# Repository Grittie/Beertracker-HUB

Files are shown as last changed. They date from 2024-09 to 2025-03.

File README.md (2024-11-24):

# IoT Start Project

This is your IoT Gitlab project. You can use it to store your code and documentation. 

## Getting Started

This project contains a setup using Docker. This will help you setup all the necessary tools to start developing your IoT project.
Before you run the docker-compose command, make sure you have to make changes to the configuration. You can find these in
the `.env` file.

Now, to install and start your project; run the following command in the root of your project:

```bash
docker-compose up -d
```

If everything runs correctly, you should be able to visit your website at [http://localhost/](http://localhost/).

## Structure

There is a specific structure that you should follow when developing your project. This will help you to keep your project organized and easy to understand.

**Documentation**

All the documentation of your project should be placed in the `docs/` folder. This will be used for your portfolio-website.

```bash
├── docs/
```

**Embedded**

Everything you need to run your embedded application should be placed in the `embedded/` folder. This includes the source code like .ino-files from Arduino.

```bash
├── embedded/
```

**Web**

Everything you need to run your web application should be placed in the `web/` folder. This includes the source code like PHP, HTML, CSS, Javascript and images.

```bash
├── web/
```

You can visit your website by going to [http://localhost/](http://localhost/) in your browser. And you can find your IoT dashboard at [http://localhost/dashboard](http://localhost/dashboard).

## Database details

The database is a MySQL database using MariaDB. You can connect to it using the following details:

| Parameter | Value |
| --- | --- |
| Host | `mariadb` (from PHP) `localhost` (from your laptop) |
| Port | `3306` |
| Username | `root` |
| Password | You can find this in your .env-file. |
| Database | You need to create the database yourself. |

## Pages
The documentation github page can be found [here](https://grittie.github.io/Beertracker-HUB/)

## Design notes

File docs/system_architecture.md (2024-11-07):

## **System Architecture**

### **Introduction**

The **System Architecture Diagram** provides an abstraction of the entire clock-in/clock-out system. It shows the interaction between the embedded system (ESP32-S3), frontend, backend, database, and the networking components. This diagram is essential to understand how the hardware and software components are connected, enabling smooth communication and efficient logging of user check-ins/outs and sensor data (e.g., temperature and humidity). This architecture also ensures the system is scalable and maintainable for future expansions.

### **Component Breakdown and Functionality**

#### **Embedded System (Subsystem)**

- **ESP32-S3-WROOM-1** (Hardware Component): The core microcontroller responsible for controlling the RFID scanning, user interaction through buttons and LEDs, and communicating with the backend system. It also handles temperature and humidity data acquisition via the DHT11 sensor.
  
- **PN532 RFID Reader** (Hardware Component): This module scans RFID cards and retrieves user information for clocking in and out. It communicates with the ESP32 via I2C.

- **DHT11 Sensor** (Hardware Component): A temperature and humidity sensor that continuously monitors the environment and sends data to the ESP32.

- **Buzzer/LEDs** (Hardware Components): Provide user feedback during operations, such as successful or failed RFID scans.

- **C/C++ Program** (Software Component): The firmware running on the ESP32 that handles input from the sensors, communication with the web server, and control of the system’s outputs (LEDs, buzzer).

#### **Webserver (Subsystem)**

- **NGINX Web Server**: Acts as a reverse proxy, directing traffic to the backend PHP services that handle API requests.
  
- **PHP Module** (Software Component): Responsible for processing HTTP requests, interacting with the database, and managing user sessions.

#### **Frontend (Subsystem)**

- **HTML Files** (Software Components): Define the structure of the web interface where users can view their clock-in/clock-out records and session data.

- **CSS Files** (Software Components): Provide the styling and layout for the web interface.

- **JavaScript Files** (Software Components): Handle frontend logic, fetch data from the backend (using AJAX/HTTP requests), and update the page dynamically.

- **Frontend PHP Files** (Software Components): Handle the dynamic generation of the HTML content, ensuring the frontend is connected to the backend API.

#### **Backend (Subsystem)**

- **API PHP Files** (Software Components): These files handle the logic for user authentication, session management, and communication with the embedded ESP32 system. The `api.php` delegates requests to handlers (e.g., `temperature_handler.php`, `card_handler.php`, `session_handler.php`) based on the type of data being processed.

- **Backend Libraries** (Software Components): These libraries provide support for managing sessions, database queries, and user authentication.

#### **Database System (Subsystem)**

- **MariaDB Database**: Stores all user data, RFID card associations, session logs, and temperature readings. Each session includes data like the check-in/check-out time and the number of pitchers.

- **Database Instance**: The actual instance running within a Docker container, handling all the persistent data storage.

#### **Docker Registry (External System)**

- **Docker Images**: Pre-built containers for PHP, MariaDB, and supporting services, facilitating a portable and consistent environment across development and production.

#### **Docker Host (Subsystem)**

- **Docker Network** (Virtual Hardware Component): Provides network communication between containers running the webserver, backend, and database services.

- **Docker Containers** (Virtual Hardware Component): Run the isolated instances of the webserver (NGINX + PHP) and MariaDB database.

#### **Host System (Subsystem)**

- **Linux (or your specific host OS)**: The operating system running the Docker containers and managing the clock-in/clock-out system.

#### **Mobile Device (External System)**

- **Mobile OS (e.g., Android/iOS)**: Allows users to interact with the system via a web browser to view their clock-in and clock-out logs.

- **Browser**: Accesses the frontend web interface for monitoring and interacting with the system.

#### **Network Access Point (External System)**

- **Wi-Fi Access Point**: Connects the ESP32 to the local network, enabling it to communicate with the backend server over HTTP.

#### **Internet/Intranet (Abstraction)**

- **Cloud Symbol**: Represents the internet or intranet that connects the mobile devices and ESP32 to the server.

#### **SSH Tunnel (Subsystem)**

- **SSH Tunnel**: Provides secure remote access to the server, allowing you to manage and monitor the system from external networks.

---

### **Communication Overview**

- **I2C Protocol (ESP32 <-> PN532, DHT11)**: Used for the ESP32 to communicate with the RFID reader and temperature sensor.
  
- **HTTP Protocol (ESP32 <-> Webserver)**: The ESP32 sends RFID data, user credentials, and sensor data via HTTP requests to the PHP backend.
  
- **HTTPS Protocol (Browser <-> Webserver)**: Users access the frontend interface over HTTPS to ensure secure transmission of data.

- **MySQL Protocol (PHP Backend <-> MariaDB)**: Used by the backend PHP files to query and store data in the database.

- **Docker Networking (Internal)**: Communication between Docker containers (NGINX, PHP, MariaDB) happens over an internal network using standard Docker networking mechanisms.

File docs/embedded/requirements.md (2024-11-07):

# Requirements

This document outlines the hardware *and* functional requirements for the **Smart Time Registration Device**. The system is based on an ESP32-S3-DevKitC-1-N8R8 and is designed to handle RFID-based user identification, API communication, provide user interaction through buttons to cycle between actions, LEDs, and a buzzer.

---

## Hardware Components

- **Microcontroller**: ESP32-S3-DevKitC-1-N8R8
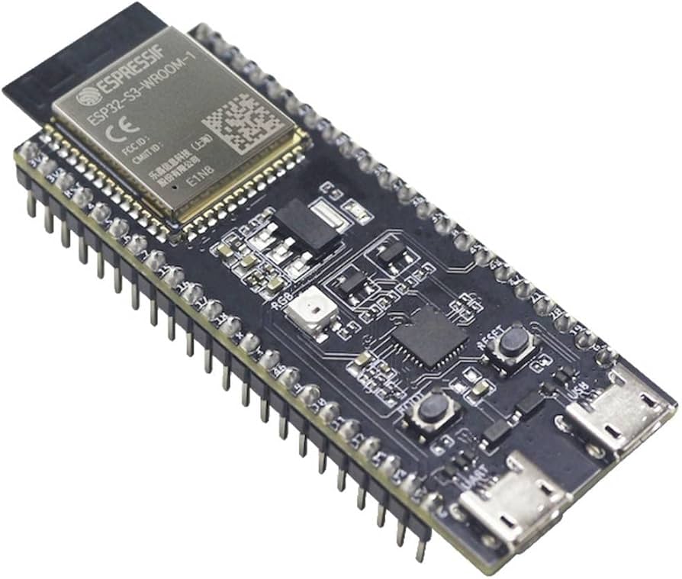
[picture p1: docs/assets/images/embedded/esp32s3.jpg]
Image of an ESP32
<br> 

- **RFID Sensor**: RFID-RC522 for scanning HVA IDs
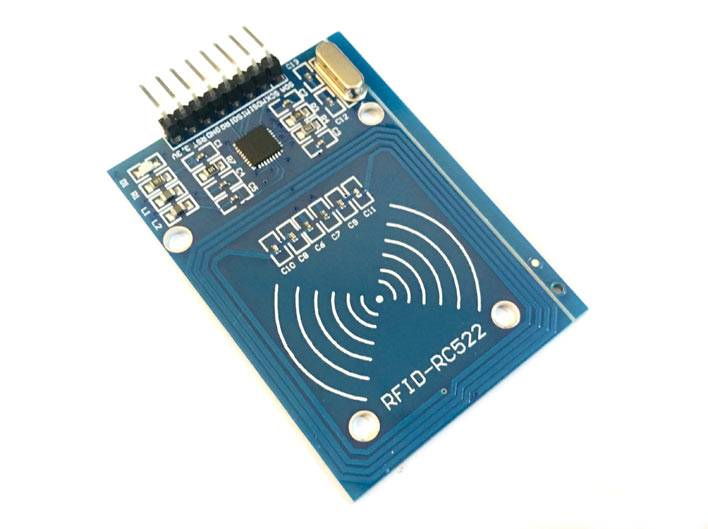
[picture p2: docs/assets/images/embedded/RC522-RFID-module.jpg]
Image of a RFID-RC522 Sensor
<br> 

- **LCD Display**: 16x2 LCD with I2C Backpack
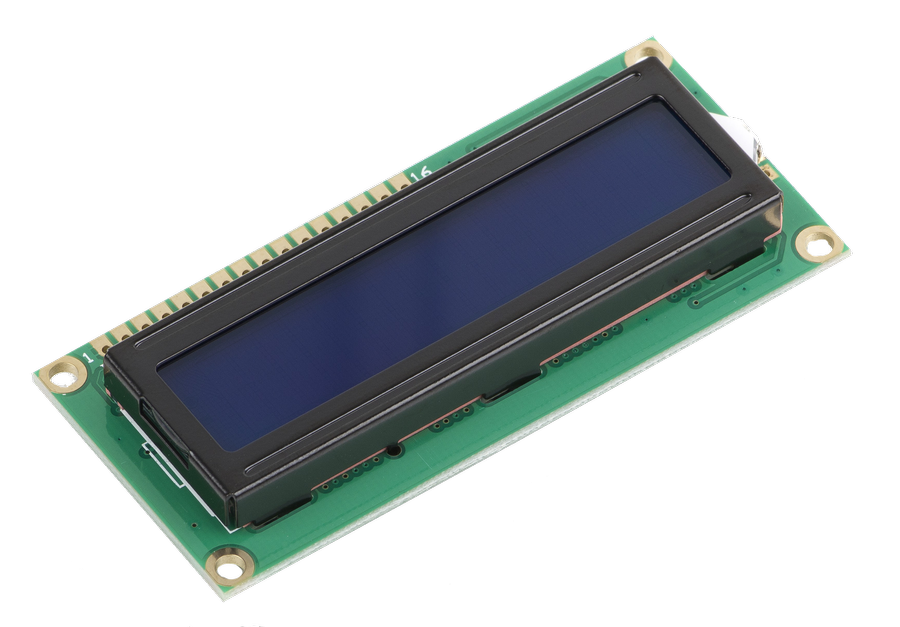
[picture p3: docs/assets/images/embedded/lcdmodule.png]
Image of a 16x2 LCD
<br> 

- **Buzzer**: For feedback on card scan
- **LEDs**: Multiple for system status indication
- **Buttons**: For switching between actions (e.g., Clock In, Clock Out, Start Break, End Break)
- **Connectivity**: Wi-Fi for making API calls to the website
---

## Functional Requirements

### 1. **RFID Scanning**
   - The system will use the RFID-RC522 RFID sensor to scan user HVA IDs.
   - Upon scanning, the system will push the ID data via an API call.

### 2. **API Communication**
   - The ESP32-S3 will connect to the internet to make API calls:
     - **Send scanned data** (RFID) to the server.
     - **Receive user data** (e.g., user name) in response and display on the LCD.

### 3. **Display and Feedback**
   - The LCD screen, connected via I2C, will show user information and action statuses.
   - The buzzer will sound when a card is successfully scanned.
   - LEDs will provide status indications for:
     - Power (system turned on)
     - Internet connectivity (connected/disconnected)
     - Card scan status (success/failure)

### 4. **User Input and Actions**
   - The system will have buttons to switch between different actions:
     - Clock In
     - Clock Out
     - Start Break
     - End Break

---

## Inputs and Outputs

| **Component** | **Type**  | **Function** |
|---|---|---|
| **ESP32-S3-DevKitC-1-N8R8** | MCU | Microcontroller to handle processing and communication. |
| **RC522** | Input | Reads RFID cards to identify users. |
| **LCD Display** | Output | Displays the user name and system statuses. |
| **Buzzer** | Output | Emits sound on successful card scan. |
| **LEDs** | Output | Shows system status: Power, Internet Connectivity, and Card Scan result. |
| **Buttons** | Input | Allows the user to switch between actions (Clock In, Clock Out, etc.). |

---

## System Workflow

1. **Power On**: System starts, LEDs indicate power and system status.
2. **Internet Connection**: LED indicates when the system is connected to the internet.
3. **RFID Scan**: User scans their ID card using the RC522 sensor.
4. **API Call**: The ESP32-S3 sends the RFID data to the server via API.
5. **API Response**: System receives user information and displays it on the LCD screen.
6. **Action Selection**: User selects the action (Clock In/Out, Start/End Break) via buttons.
7. **Feedback**: Buzzer sounds when a card is scanned, LEDs change based on status (e.g., card scan success).

---

## DLO Requirements

| **Requirement ID#** | **Requirement** | **MoSCoW** | **Compliant** |
|---|---|---|---|
| **EMBRQ#01** | The embedded device acts as a client and sends measured sensor data to the application backend over HTTP or HTTPS. | MUST | YES |
| **EMBRQ#02** | The embedded device also acts as a server and receives status messages from the application backend over HTTP or HTTPS. | MUST | YES |
| **EMBRQ#03** | The embedded device contains at least two types of input sensors (e.g. LDR, buttons, joystick, capacitive touch, etc.). | MUST | YES |
| **EMBRQ#04** | The embedded device contains at least two types of visual and/or sensory outputs (e.g. LED, LED Matrix, 7-segment display, motor, servo, actuator, LCD-screen, buzzer, etc.). | MUST | YES |
| **EMBRQ#05** | The embedded device uses the WifiManager for configuration of SSID and password (PWD) for connecting to the network. | MUST | YES |

---

### EMBRQ#01

**Requirement**: The embedded device acts as a client and sends measured sensor data to the application backend over HTTP or HTTPS.

**Explanation**:  
The code uses the `HTTPClient` library to send data to the backend API. This is implemented through a function that collects temperature and humidity data from the DHT sensor and then sends it using an HTTP POST request to the server.

**Code**:
```cpp
#include <HTTPClient.h>
#include <DHT.h>

#define TEMP_SENSOR 26 // Analog Pin
#define DHTTYPE DHT11  // DHT 11 type sensor

DHT dht(TEMP_SENSOR, DHTTYPE);

void sendSensorData() {
    HTTPClient http;
    String serverPath = "http://your-server.com/api.php";
    
    // Read temperature and humidity
    float temperature = dht.readTemperature();
    float humidity = dht.readHumidity();

    // Start connection and send HTTP header
    http.begin(serverPath);
    http.addHeader("Content-Type", "application/json");
    
    // Create JSON payload
    String jsonPayload = "{"temperature": " + String(temperature) + ", "humidity": " + String(humidity) + "}";
    int httpResponseCode = http.POST(jsonPayload);
    
    // End connection
    http.end();
}
```

---

### EMBRQ#02

**Requirement**: The embedded device also acts as a server and receives status messages from the application backend over HTTP or HTTPS.

**Explanation**:  
The code uses the `ESPAsyncWebServer` library to create an HTTP server on the ESP32. The server can receive status messages from the backend, which are processed by specific request handlers.

**Code**:
```cpp
#include <ESPAsyncWebServer.h>

AsyncWebServer server(80);

void setup() {
    // Start server
    server.on("/status", HTTP_POST, [](AsyncWebServerRequest *request) {
        String message;
        if (request->hasParam("status", true)) {
            message = request->getParam("status", true)->value();
            // Handle status update
        }
        request->send(200, "text/plain", "Status received");
    });
    server.begin();
}
```

---

### EMBRQ#03

**Requirement**: The embedded device contains at least two types of input sensors (e.g. LDR, buttons, joystick, capacitive touch, etc.).

**Explanation**:  
The embedded device uses both an RFID sensor (`MFRC522`) and a DHT11 sensor as input devices. The RFID sensor is used to read card data, while the DHT11 sensor measures temperature and humidity.

**Code**:
```cpp
#include <MFRC522.h>
#include <DHT.h>

#define SS_PIN 5    // SDA/SS Pin for SPI
#define RST_PIN 17  // Reset Pin for SPI
#define TEMP_SENSOR 26 // Analog Pin
#define DHTTYPE DHT11  // DHT 11 type sensor

MFRC522 mfrc522(SS_PIN, RST_PIN);
DHT dht(TEMP_SENSOR, DHTTYPE);

void setup() {
    SPI.begin();
    mfrc522.PCD_Init();
    dht.begin();
}
```

---

### EMBRQ#04

**Requirement**: The embedded device contains at least two types of visual and/or sensory outputs (e.g. LED, LED Matrix, 7-segment display, motor, servo, actuator, LCD-screen, buzzer, etc.).

**Explanation**:  
The embedded device uses an LCD display (`LiquidCrystal_I2C`) to show status messages and a buzzer for auditory feedback. The LCD provides visual output, while the buzzer is used for alerts or notifications.

**Code**:
```cpp
#include <LiquidCrystal_I2C.h>

#define BUZZER_PIN 25 // Buzzer Pin

LiquidCrystal_I2C lcd(0x27, 16, 2);

void setup() {
    lcd.init();
    lcd.backlight();
    pinMode(BUZZER_PIN, OUTPUT);
    
    // Example usage
    lcd.setCursor(0, 0);
    lcd.print("Welcome!");
    digitalWrite(BUZZER_PIN, HIGH); // Sound the buzzer
    delay(500);
    digitalWrite(BUZZER_PIN, LOW);
}
```

---

### EMBRQ#05

**Requirement**: The embedded device uses the WifiManager for configuration of SSID and password (PWD) for connecting to the network.

**Explanation**:  
The `WiFiManager` library is used to manage the Wi-Fi connection. If no known SSID is found, the device will start an access point, allowing the user to configure the Wi-Fi credentials via a web interface.

**Code**:
```cpp
#include <WiFiManager.h>

void setup() {
    WiFiManager wifiManager;
    // Automatically connect using saved credentials, or start AP for configuration
    wifiManager.autoConnect("BeertrackerAP");
}
```

---

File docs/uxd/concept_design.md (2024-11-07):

# Concept & Design

## Concept

The **Smart Check in / out system** is being developed for [beertracker.nl](http://beertracker.nl) , a platform used by students of the Amsterdam University of Applied Sciences (HvA). The system helps track beer ordering so that everyone pays equally without needing to request payments after the fact.

### Main Goal

As an HvA student using beertracker.nl, my primary goal is to ensure that the consumption and ordering of beer is tracked accurately so I can pay my fair share without having to manually calculate or request payments from others. I want a simple and efficient way to clock in when I start drinking and clock out when I'm done, knowing that the system will automatically track how much I've ordered and what I owe, ensuring fair and equal payments among all participants.

### Product Requirements

The clock in and clock out system for beertracker.nl will meet the following SMART requirements:

**Specific**:

- The system must enable users (HvA students) to clock in when they start drinking and clock out when they finish.
- It must track each user's drinking session, log the start and end times, and calculate the total beer ordering for each user.

**Measurable**:

- The system must record at least 95% of drinking sessions without error and provide clear consumption and payment data for each user.
- It will display the total number of users who have clocked in, total consumption per session, and individual ordering per user.
- The system will update the main dashboard and provide a history of each session.

**Achievable**:

- The system will use RFID tags to allow users to clock in and out quickly, minimizing manual input.
- It will integrate with the existing beertracker.nl website to synchronize consumption data in real-time.

**Relevant**:

- The system directly addresses the students' need for a fair, automated way to track beer consumption.
- It reduces the complexity of keeping track of who owes what, ensuring a hassle-free experience for social drinking events.

**Time-bound**:

- The system will be fully implemented and tested by the end of the 10-week project period.

### Users

The primary users of this system are HvA students in their third year. They need a system that can accurately track the order of beer in a fair and automated way, ensuring that payments are distributed equally among all users.

#### Scope

- The system will only be used by HvA students in their (current) third year.
- The scope includes beer (pitcher) order tracking, clocking in and out of sessions, and easy access to consumption data.

### User Needs

#### SMART Goals

- **Specific**: The system must allow students to clock in when they start drinking and clock out when they stop, accurately logging consumption times and calculating how much each person owes.
- **Measurable**: The system should record the number of users and total beer consumption during each session.
- **Achievable**: The solution will be implemented using RFID scanning of HvA IDs to make clocking in and out simple and quick.
- **Relevant**: This system directly addresses the problem of unequal beer consumption and payment confusion among students.
- **Time-bound**: The system should be operational by the end of the 10-week project period.

<br>

## Digital Manufacturing & Material

For the **Smart Check in / out system** encasing, I will be 3D printing the housing using **PLA (Polylactic Acid)** on my personal **Bambu Labs A1 Mini** due to its ideal properties for this type of project.

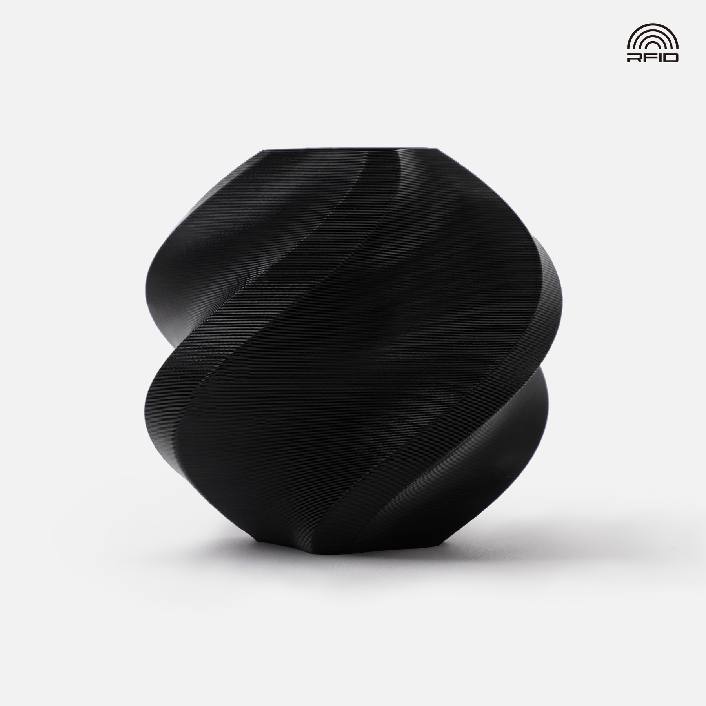
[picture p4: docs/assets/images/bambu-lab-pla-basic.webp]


### Material Properties

- **Strength**: PLA provides fine structural integrity for a device that won't be used in high-impact environments. It will also be mobile and not have to weather the elements. However, if more structural strength is required, I have the option to use **carbon-infused filament**, which offers enhanced durability and stiffness.

- **Ease of Use**: PLA is easy to print and works well with the Bambu Labs A1 Mini, making it perfect for quickly prototyping and iterating the design. It is odorless, inexpensive, and readily available.

- **Precision**: With the A1 Mini, the design details such as RFID scanner cutouts, button placements, and ventilation for sensors will be aligned with high accuracy, ensuring a perfect fit.

- **Environmental Consideration**: PLA is eco-friendly, being derived from renewable resources and can be reformed into more spools.

- **Speed of Production**: The Bambu Labs A1 Mini is a fast and reliable printer, allowing me to quickly produce and test multiple versions of the enclosure.

<br>

## Design Sketches

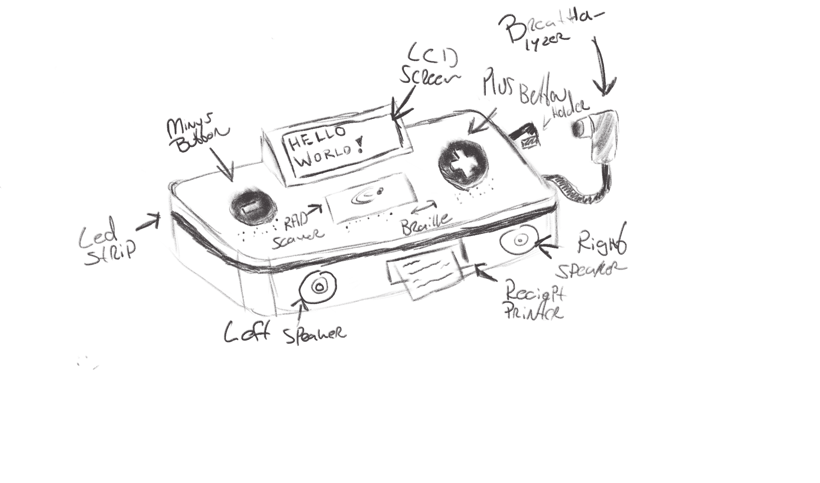
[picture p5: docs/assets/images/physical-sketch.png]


## Digital Design

For the digital design of the encasing, I am using **Onshape**, a cloud-based CAD platform. Onshape provides several advantages for this project:

- **Browser-Based Access**: Since Onshape runs entirely in a web browser, I can access and modify my designs from any device with an internet connection, eliminating the need for specialized hardware or software installations.
- **Ease of Use**: Its intuitive interface and powerful set of tools make creating complex 3D models straightforward, ensuring the encasing design fits all internal components accurately.
- **Version Control**: Onshape tracks every change made to the design, allowing me to easily revert to previous versions or compare different iterations.
- **Plug-In Support**: Onshape allows for easy integration of plug-ins, enabling me to extend functionality with additional tools and features as needed during the design process.

All CAD designs related to this project can be found in the **/cad** folder in the root directory of this project, where each design iteration is documented and available for review.

### CAD Design

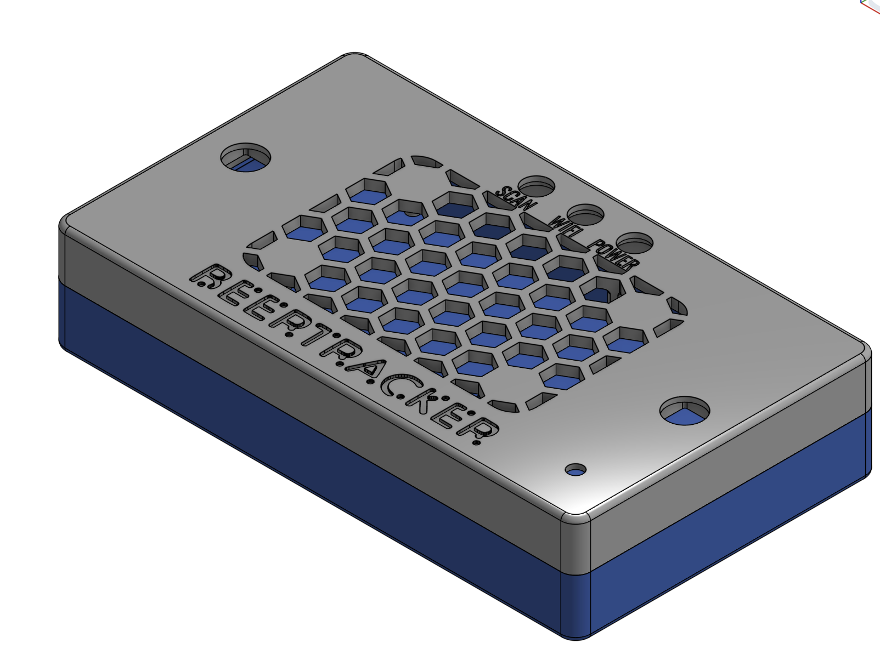
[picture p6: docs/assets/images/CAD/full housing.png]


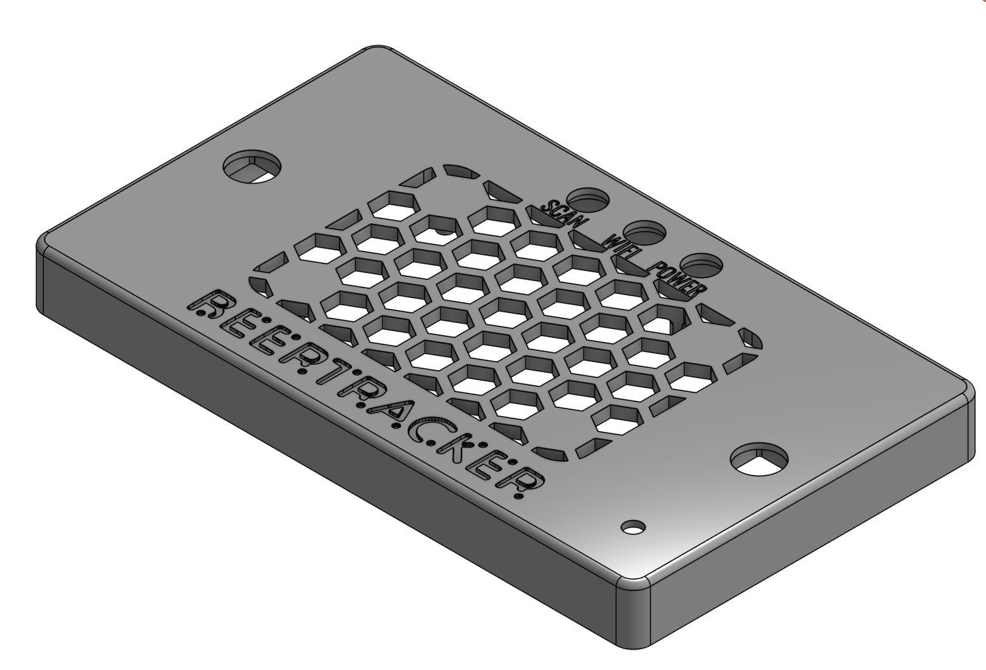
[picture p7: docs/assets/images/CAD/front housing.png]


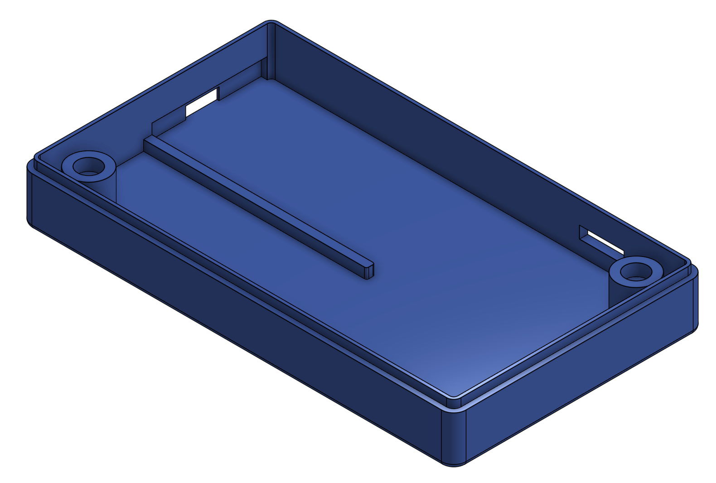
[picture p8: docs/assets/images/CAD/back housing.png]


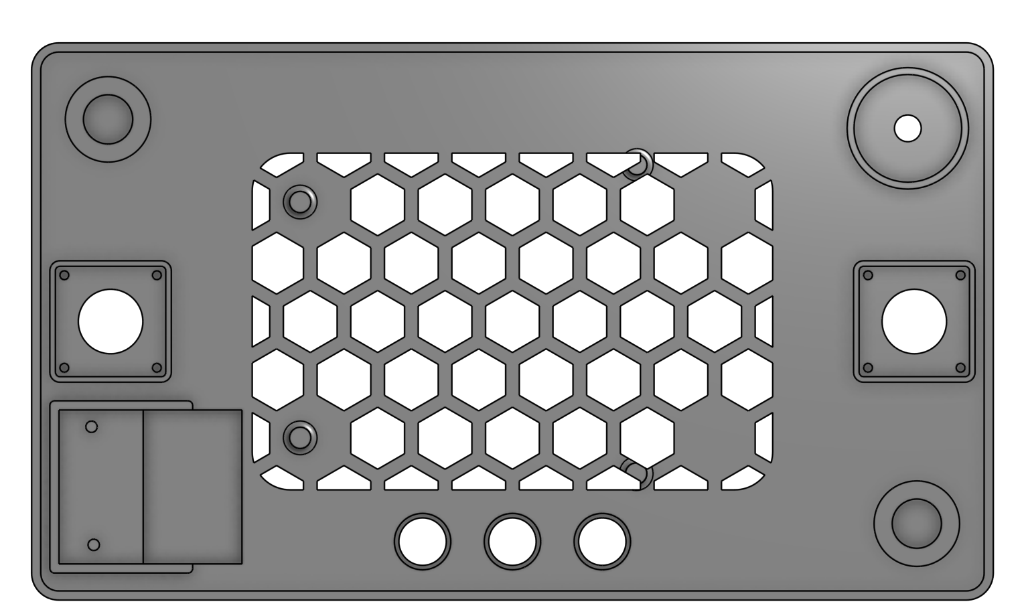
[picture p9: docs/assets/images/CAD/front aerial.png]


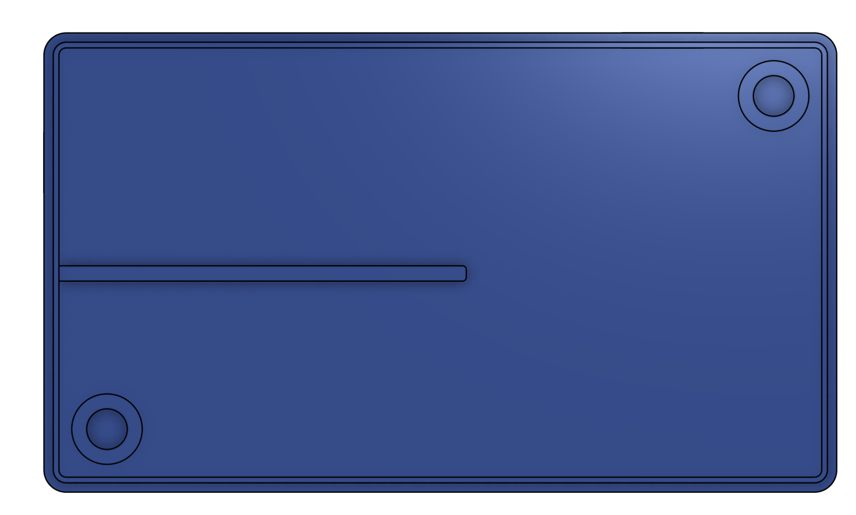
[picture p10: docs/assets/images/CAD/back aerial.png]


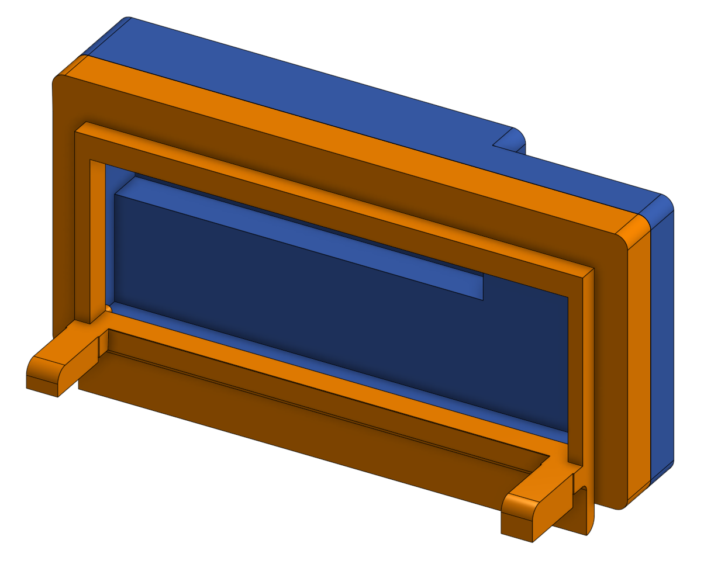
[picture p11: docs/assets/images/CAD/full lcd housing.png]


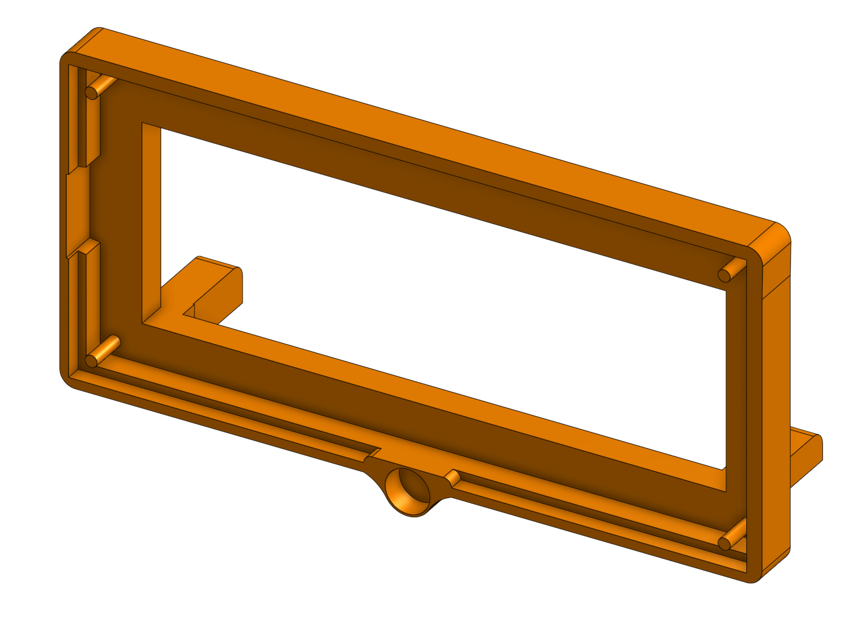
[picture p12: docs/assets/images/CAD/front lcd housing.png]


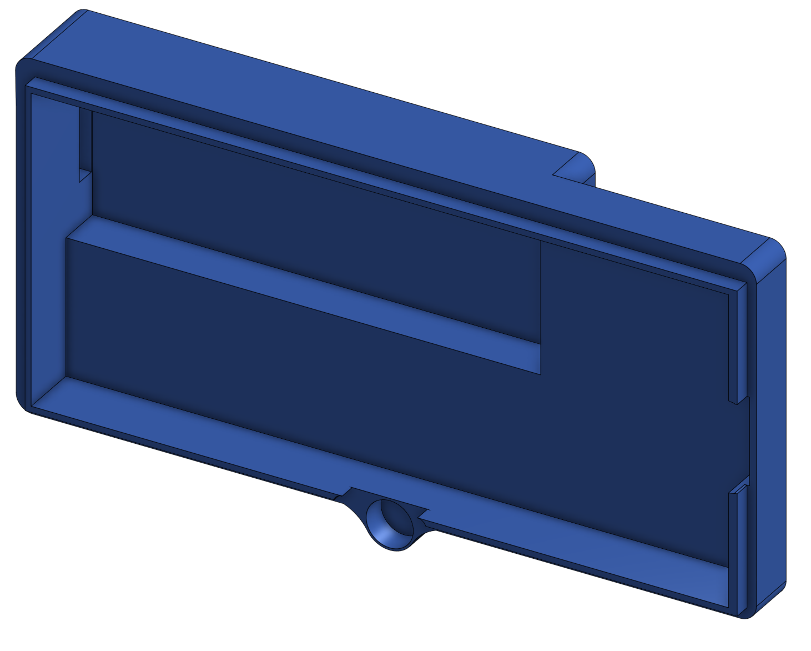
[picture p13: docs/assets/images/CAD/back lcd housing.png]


All versions of the design files that were created and that are described in this documentation can be found in the **/cad** folder in the root of the project.

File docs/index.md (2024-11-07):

# Smart Time Registration

## What is a Time Registration Device?
The Smart Time Registration device is a tool used to track the ammount of time an employee has spent working, it can take on many forms. Traditionally, this was a a physical time clock where employees would 'punch in and out' their card, recording their hours manually.

Nowadays, time registration devices are often available as websites or mobile apps. These tools can not only track overall work hours but also allow users to log time spent on specific tasks or projects. This tracking is then used for billing purposes, project management, and ensuring accurate payroll processing.

## The vision
TODO: work on this
I want the device to work like this and look something like this and work this way etc etc

## Project Requirements
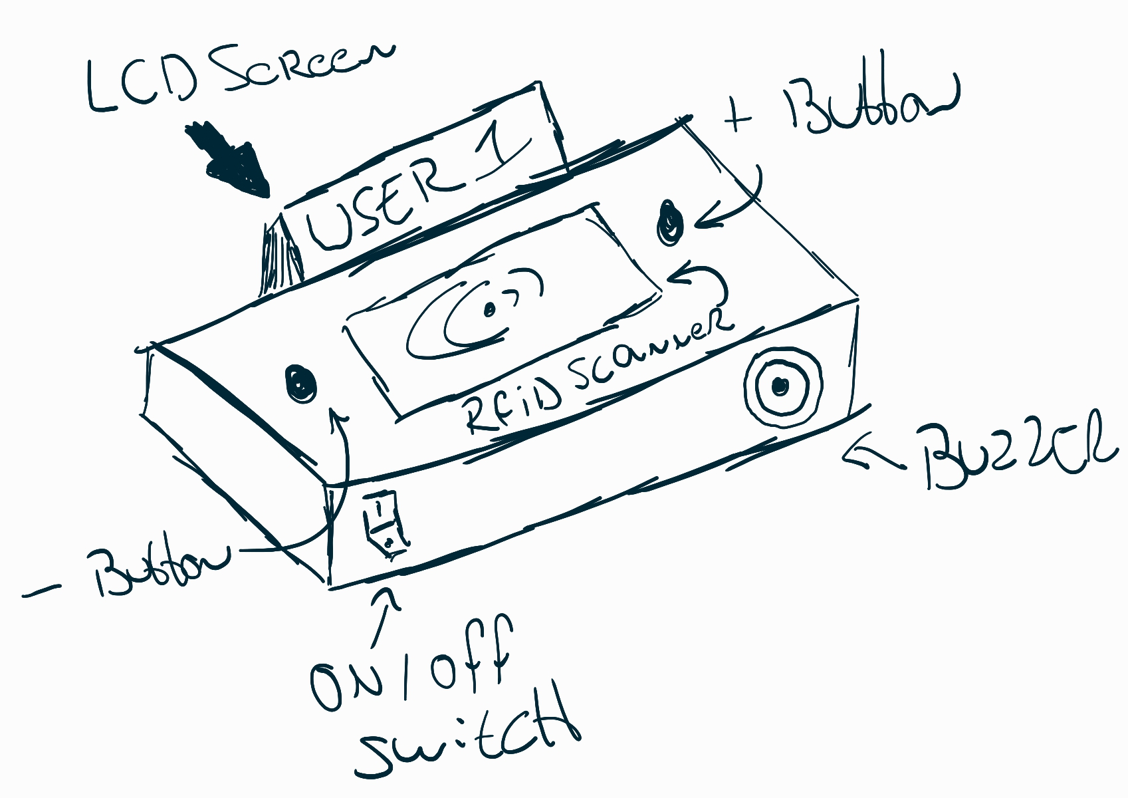
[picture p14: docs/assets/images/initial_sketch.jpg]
Initial sketch of the device


(image will be changed  when better sketches are available)

### Embedded Device
For this project, the ESP32, along with other devices, will serve as the core component of the embedded product. Various sensors and peripherals, including an RFID scanner for scanning students' HVA IDs, buttons, and displays for data visualization, will be connected to the ESP32.

#### The 3 minimum requirement for Input & Ouput are:
**INPUT:**

1. RFID Scanner

2. Buttons for increment and decrement (plus & minus)

3. On / Off Switch

**Output:**

1. LED Indicators

2. LCD Screen

3. Passive Buzzer

### Website

The website will implement user registration using HVA IDs and passwords. Users will be listed with their clock-in and clock-out times for the day. Further developments and applications of this data are to be determined.

### User Experience Design (CAD)

The device will be housed in a compact enclosure designed using CAD, with the software OnShape.

---

## Market Research
Once the blueprint requirements are met, the device will be changed adding our own flavor and features. For example, a counter registration system will be integrated to track beverages, which will be added to a user database when they scan their pass. The device will also be integrated into a already running project "BeerTracker". 

## What is BeerTracker?

BeerTracker is a website designed, made and managed by Lars Grit for his class at the University of Applied Science of Amsterdam to keep a track of how many beers have been bought and drank to avoid the classic tradition of "tikkies". Using the BeerTracker the class is made aware of how much people are chipping in to keep the drinks even.

During the implementation of this device the website will be heavily changed and updated.

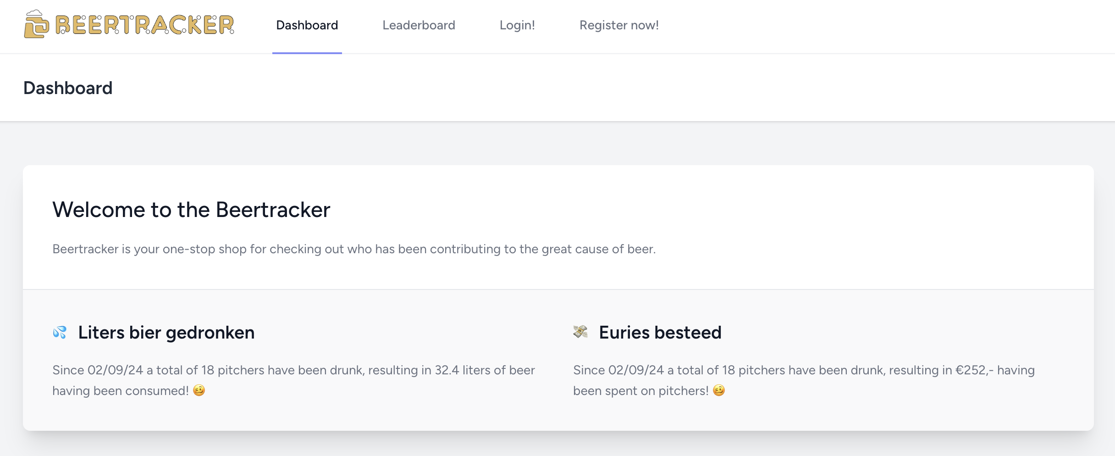
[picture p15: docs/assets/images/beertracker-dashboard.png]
The dashboard of beertracker.nl


---

## Project Plan

Throughout the duration of the project, I will be working on various aspects in parallel, rather than focusing on just one area each week. However, by the end of each week, I aim to have completed the specific tasks and milestones outlined for that week.

### **Week 1: Initial Setup**
- Set up the fundamental components of the project, including hardware like the ESP32, RFID sensors, etc and environment, and software like setting up platformIO, Docker, and python for the Portfolio Website.

### **Week 2: Network and Website Integration**
- Connect the esp32 to the network and work on data communication.
- Setup REST-API
- Develop a basic website that interfaces with the clock-in and clock-out system, getting data from the database.

### **Week 3: CAD Housing Design**
- Design and create a CAD model for the housing of the device to ensure everything fits well within the enclosure.

### **Week 4: Blueprint Finalization**
- Finalize the overall project blueprint, including diagrams, wiring, and database structure.

### **Week 5: Market Research and Beer Tracker Integration**
- Conduct market research to assess project feasibility and potential features.
- Explore integration with beertracker.

### **Week 6: User Experience Design & Branding**
- Expand on the User Experience Design, focusing on improving usability and user interface.
- Start adding branding elements, making the project aesthetically appealing.

### **Week 7: Web Development**
- Focus on refining the web interface, enhancing functionality, and integrating with beertracker.nl.

### **Week 8: Additional Features (Alcohol Sensor)**
- Add nice-to-have features like an alcohol sensor to track usage and safety.
- Work on UED, web enhancements, and embedded system improvements for this new feature.

### **Week 9: Final Feedback**
- Gather and implement feedback from peers, teachers, and potential users to fine-tune the system.

### **Week 10: Project Finalization**
- Finalize the project, ensuring all features are tested, the device is functioning as intended, everything is documented, `and everything is ready for production.

--- 

## Use of AI
The use of AI has been used writing this project to improve readability with better grammar 

{{ mdocotion_header('https://cdn.prod.website-files.com/65730eadde5e46a394ae1451/65730eadde5e46a394ae14ca_ES%20-%20Image%20home%202.jpg') }}

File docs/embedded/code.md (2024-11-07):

# Embedded Code Documentation

This document provides a detailed explanation of the embedded code implementation found in the file [`main.cpp`](https://gitlab.fdmci.hva.nl/IoT/2024-2025-semester-1/individual-project/zuuliiyiizoo76/-/blob/main/embedded/iot-embedded/src/main.cpp). The goal is to describe both the general functionality and specific elements of the code to provide a deeper understanding of its workings.

## General Overview

The `main.cpp` file is the main entry point for an embedded system application. This code manages various functionalities of an IoT clock in and clock out system. The system is built around an ESP32-S3 microcontroller, which integrates multiple peripheral devices such as an RFID scanner, an I2C display, LEDs, buttons, and environmental sensors.

The code is structured to set up all peripherals and handle their operations efficiently using tasks and interrupts, leveraging the FreeRTOS multithreading environment. The implementation is designed to manage different actions, such as user authentication, environmental monitoring, and session management, all of which are coordinated through the central processing flow in `main.cpp`.

## Code Structure

### 1. **Libraries and Constants**

The code begins with importing the necessary libraries for handling different modules connected to the ESP32-S3, including:
- **Wire library** for I2C communication.
- **SPI library** for communication with RFID.
- **FreeRTOS-specific libraries** for task management.
- **Custom header files** that encapsulate specific device-related functionality like LCD, RFID, etc.

Several constants are defined for pins used, such as the SDA, SCL pins for I2C devices, and GPIO pins for LEDs, buttons, and RFID communication.

### 2. **Setup Function**

The `setup()` function is where all initialization happens. The steps include:
- **Initializing Serial Communication:** Primarily for debugging purposes.
- **RFID Initialization:** The RFID sensor is initialized, and its configuration is verified.
- **Display Initialization:** The I2C LCD screen is set up to display messages and provide feedback to the user.
- **Pin Configuration:** The pins for LEDs and buttons are set as input or output as required.
- **WiFi Connection Setup:** The code uses WiFiManager for connecting the ESP32 to the network, which enables communication with a backend server.

### 3. **Loop Function**

The `loop()` function typically contains the main execution cycle for an Arduino program, but in this case, it remains empty. Instead, the real functionality is executed using FreeRTOS tasks to achieve concurrent behavior.

### 4. **FreeRTOS Task Management**

The implementation uses several FreeRTOS tasks:
- **RFID Reading Task:** A task that continuously polls the RFID scanner to detect card taps and retrieve the UID. When a card is successfully scanned, the UID is sent to a backend server for validation and session management.
- **Environmental Monitoring Task:** This task reads data from the DHT11 temperature and humidity sensor and sends the data to the backend periodically.
- **Display Update Task:** Manages updating the LCD screen, such as displaying welcome messages, errors, or user-specific information when authenticated.
- **HTTP Server Task:** This task sets up an HTTP server to handle incoming requests from the web interface.

### 5. **Button Handling and Interrupts**

The code handles button presses using interrupts for better responsiveness. Two buttons are used to perform different actions:
- **Clock In Button:** Assigned to GPIO pin 20, it allows users to check in when pressed.
- **Clock Out Button:** The other button allows users to clock out of the system.

Interrupt Service Routines (ISRs) are configured to detect rising edges for both buttons, which helps in quick and accurate user interaction.

### 6. **WiFi Communication and Backend Integration**

Data such as RFID UIDs and temperature readings are sent to the backend using HTTP requests. The backend API handles data such as temperature (`temperature_handler.php`) or user sessions (`session_handler.php`). The integration with the backend allows storing the data centrally and generating reports for logged sessions.

### 7. **HTTP Server for Remote Reset**

The implementation includes an HTTP server task (`httpServerTask`) that enables remote interaction with the ESP32 through a web interface. One notable feature is the ability to reset the ESP32 remotely by sending an HTTP POST request to the `/reset` endpoint. When this endpoint is triggered, the server sends a response confirming the reset and then calls `ESP.restart()` to reset the microcontroller.

This feature is particularly useful for remotely troubleshooting or rebooting the device without needing physical access, ensuring that any configuration changes or software updates can be applied effectively.

```cpp
void httpServerTask(void *pvParameters) {
    server.on("/reset", HTTP_POST, [](AsyncWebServerRequest *request) {
        request->send(200, "text/plain", "ESP32 is resetting...");
        ESP.restart();
    });

    server.begin();

    while (true) {
        delay(1000);
    }
}
```

### 8. **Error Handling**

Error handling is present in various functions, especially for device initialization and communication failures. If, for example, the RFID sensor fails to initialize, the system will show an error message on the display and prevent further operations until the error is resolved.

## Notable Features

- **Multithreading with FreeRTOS:** The use of FreeRTOS tasks enables the system to perform multiple actions simultaneously, such as scanning RFID tags while reading environmental data and updating the display.
- **Real-Time Updates:** The use of interrupts for buttons ensures that the system responds to user inputs in real time without noticeable delay.
- **Backend API Communication:** The ESP32 communicates with a backend server, enabling seamless logging of user sessions and temperature monitoring, which is essential for remote monitoring and analysis.
- **Remote Reset Capability:** The HTTP server task allows the ESP32 to be reset remotely, providing a convenient way to manage and troubleshoot the device.

## Link to Code Repository

For further information, you can refer to the code available in the repository: [main.cpp](https://gitlab.fdmci.hva.nl/IoT/2024-2025-semester-1/individual-project/zuuliiyiizoo76/-/blob/main/embedded/iot-embedded/src/main.cpp)

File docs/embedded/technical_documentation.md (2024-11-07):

# Technical documentation

## Wiring Diagram
A wiring diagram shows how components are connected. It uses symbols for parts like resistors and power sources to illustrate connections and current flow, helping with troubleshooting.

### RFID Scanning system
### Breadboard Diagram


### Schematic Diagram


## Bill of Materials (BOM)

A BOM lists all components needed for a project, including names, quantities, and specifications. It acts as a checklist for sourcing parts and assembling the system.

| Component | Description | Quantity | Price (EUR) | Supplier | Purchase Link |
|---|---|---|---|---|---|
| **Perfboard** | Prototyping board for soldering components | 1 | €1.95 | TinyTronics  | [Perfboard 7x9cm - Single Sided](https://www.tinytronics.nl/en/prototyping-and-installation/prototyping-supplies/perfboards/perfboard-7x9cm-single-sided) |
| **Bambu Lab PLA Matte White** | Matte white PLA filament for 3D printing | 1 | $19.99 | Bambu Lab | [Bambu Lab PLA Matte - Ivory White](https://store.bambulab.com/en/products/pla-matte-filament) |
| **Bambu Lab PLA Basic Yellow** | Basic yellow PLA filament for 3D printing | 1 | $19.99 | Bambu Lab | [Bambu Lab PLA Basic - Sunflower Yellow](https://store.bambulab.com/en/products/pla-basic-filament) |
| **RFID RC522 Module** | RFID reader module for reading RFID tags | 1 | €4.95 | TinyTronics  | [RFID Kit MFRC522 S50 Mifare with Card and Key Tag](https://www.tinytronics.nl/en/communication-and-signals/wireless/rfid/rfid-kit-mfrc522-s50-mifare-with-card-and-key-tag) |
| **16x2 LCD Screen** | 16x2 character LCD display | 1 | €3.95 | TinyTronics  | [LCD1602 16x2 Character Display - Yellow/Green](https://www.tinytronics.nl/en/displays/lcd/lcd1602-16x2-character-display-yellow-green) |
| **I2C Backpack for LCD** | I2C interface module for LCD screens | 1 | €1.95 | TinyTronics  | [I2C Interface Module for LCD1602 and LCD2004](https://www.tinytronics.nl/en/displays/lcd/i2c-interface-module-for-lcd1602-and-lcd2004) |
| **Green LED** | 5mm green LED | 1 | €0.95 | TinyTronics  | [LED 5mm Green - 10 pieces](https://www.tinytronics.nl/en/light-and-sound/lighting/individual-leds/led-5mm-green-10-pieces) |
| **Blue LED** | 5mm blue LED | 1 | €0.95 | TinyTronics  | [LED 5mm Blue - 10 pieces](https://www.tinytronics.nl/en/light-and-sound/lighting/individual-leds/led-5mm-blue-10-pieces) |
| **Red LED** | 5mm red LED | 1 | €0.95 | TinyTronics  | [LED 5mm Red - 10 pieces](https://www.tinytronics.nl/en/light-and-sound/lighting/individual-leds/led-5mm-red-10-pieces) |
| **1kΩ Resistors** | 1k ohm resistors | 5 | €0.95 | TinyTronics  | [Resistor 1kΩ - 10 pieces](https://www.tinytronics.nl/en/components/components/resistors/resistor-1kω-10-pieces) |
| **Passive Buzzer** | Passive piezoelectric buzzer | 1 | €0.95 | TinyTronics  | [Passive Buzzer Module](https://www.tinytronics.nl/en/light-and-sound/audio/buzzer-module-passive) |
| **Jumper Wires** | Male-to-male jumper wires for prototyping | 1 set | €2.95 | TinyTronics  | [Jumper Wires Male to Male - 65 pieces](https://www.tinytronics.nl/en/prototyping-and-installation/prototyping-supplies/jumper-wires-male-to-male-65-pieces) |
| **DHT11 Sensor Module** | Temperature and humidity sensor module | 1 | €2.95 | TinyTronics  | [DHT11 Temperature and Humidity Sensor Module](https://www.tinytronics.nl/en/sensors/air/dht11-temperature-and-humidity-sensor-module) |
| **ESP32 Development Board** | ESP32 microcontroller board with Wi-Fi and Bluetooth | 1 | €7.95 | TinyTronics  | [ESP32 Development Board - WiFi and Bluetooth](https://www.tinytronics.nl/en/development-boards/esp32-development-board-wifi-and-bluetooth) |
| **Push Buttons** | Momentary push buttons | 2 | €0.95 | TinyTronics  | [Push Button 12x12mm - 5 pieces](https://www.tinytronics.nl/en/components/components/switches/manual-switches/push-button-12x12mm-5-pieces) |
| **Capacitor Assortment** | Assorted electrolytic capacitors | 1 set | €4.95 | TinyTronics  | [Electrolytic Capacitor Assortment - 24 values](https://www.tinytronics.nl/en/components/components/capacitors/electrolytic-capacitor-assortment-24-values) |
| **USB-C Cable** | USB 2.0 cable A to USB-C, 1 meter | 1 | €2.95 | TinyTronics  | [USB 2.0 Cable A to USB-C - 1 meter](https://www.tinytronics.nl/en/cables-and-connectors/cables-and-adapters/usb-cables/usb-2.0-cable-a-to-usb-c-1-meter) |
| **USB-C Wall Adapter (5V 3A)** | 5V 3A USB-C power adapter | 1 | €7.95 | TinyTronics  | [USB-C Power Adapter 5V 3A](https://www.tinytronics.nl/en/power/power-adapters/usb-c-power-adapter-5v-3a) |
| **Soldering Tin** | 0.8mm soldering tin, 100g | 1 | €9.95 | TinyTronics  | [Soldering Tin 0.8mm 100g](https://www.tinytronics.nl/en/prototyping-and-installation/prototyping-supplies/soldering-tin-0.8mm-100g) |

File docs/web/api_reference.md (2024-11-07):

# API Reference

This documentation provides a detailed overview of all available API endpoints in the system. Each endpoint's purpose, method, URL, parameters, and response structure are described to facilitate integration and usage.

---

## API Endpoints

### POST Endpoints

1. **Handle Card Session**
    - **Endpoint**: `/api/card`
    - **Method**: POST
    - **Parameters**:
      - `RFID_Tag` (string): Unique identifier for the RFID card.
    - **Description**: Processes session data associated with a card (RFID).
    - **Response Example**:
      ```json
      {
          "status": "success",
          "message": "Session processed successfully."
      }
      ```

2. **Handle Device Address**
    - **Endpoint**: `/api/address`
    - **Method**: POST
    - **Parameters**:
      - `device_id` (string): Identifier for the device.
      - `address` (string): Address details to be stored.
    - **Description**: Stores or updates the device address information.
    - **Response Example**:
      ```json
      {
          "status": "success",
          "message": "Device address updated successfully."
      }
      ```

3. **Handle Heartbeat**
    - **Endpoint**: `/api/heartbeat`
    - **Method**: POST
    - **Parameters**:
      - `device_id` (string): Identifier of the device sending the heartbeat.
    - **Description**: Logs a heartbeat signal from a device.
    - **Response Example**:
      ```json
      {
          "status": "success",
          "message": "Heartbeat recorded successfully."
      }
      ```

4. **Handle Device Connection**
    - **Endpoint**: `/api/connection`
    - **Method**: POST
    - **Parameters**:
      - `device_id` (string): Identifier of the connected/disconnected device.
      - `status` (string): Status of the device (e.g., "connected", "disconnected").
    - **Description**: Registers the connection status of a device.
    - **Response Example**:
      ```json
      {
          "status": "success",
          "message": "Device connection status recorded."
      }
      ```

5. **Add Session Data**
    - **Endpoint**: `/api/session`
    - **Method**: POST
    - **Parameters**:
      - `UserID` (int): User ID for session entry.
      - `CheckInTime` (datetime): Time of check-in.
      - `CheckOutTime` (datetime): Time of check-out.
    - **Description**: Records session data including check-in and check-out times for users.
    - **Response Example**:
      ```json
      {
          "status": "success",
          "message": "Session data recorded successfully."
      }
      ```

6. **Handle Temperature Data**
    - **Endpoint**: `/api/temperature`
    - **Method**: POST
    - **Parameters**:
      - `temperature` (float): Temperature reading from the device.
      - `humidity` (float): Humidity reading from the device.
    - **Description**: Stores temperature readings from devices.
    - **Response Example**:
      ```json
      {
          "status": "success",
          "message": "Temperature data recorded."
      }
      ```

7. **Add New User**
    - **Endpoint**: `/api/add_user`
    - **Method**: POST
    - **Parameters**:
      - `name` (string): Name of the new user.
      - `role` (string): Role of the user (e.g., "admin", "user").
      - `rfid_tag` (string): RFID tag associated with the user.
    - **Description**: Adds a new user with associated RFID tag information.
    - **Response Example**:
      ```json
      {
          "success": true,
          "message": "User added successfully."
      }
      ```

8. **Edit User**
    - **Endpoint**: `/api/edit_user`
    - **Method**: POST
    - **Parameters**:
      - `userID` (int): ID of the user to edit.
      - `name` (string): Updated name of the user.
      - `role` (string): Updated role of the user.
      - `rfid_tag` (string): Updated RFID tag.
    - **Description**: Edits user details including name, role, and RFID tag.
    - **Response Example**:
      ```json
      {
          "success": true,
          "message": "User details updated."
      }
      ```

9. **Delete User**
    - **Endpoint**: `/api/delete_user`
    - **Method**: POST
    - **Parameters**:
      - `userID` (int): ID of the user to delete.
    - **Description**: Deletes a user from the database.
    - **Response Example**:
      ```json
      {
          "success": true,
          "message": "User deleted."
      }
      ```

---

### GET Endpoints

1. **Get Connection Status**
    - **Endpoint**: `/api/connection`
    - **Method**: GET
    - **Description**: Retrieves connection status of all devices.
    - **Response Example**:
      ```json
      {
          "success": true,
          "connections": [
              { "deviceId": "ESP32-001", "status": "connected" },
              { "deviceId": "ESP32-002", "status": "disconnected" }
          ]
      }
      ```

2. **Get Heartbeat Status**
    - **Endpoint**: `/api/heartbeat`
    - **Method**: GET
    - **Description**: Fetches latest heartbeat data from devices.
    - **Response Example**:
      ```json
      {
          "success": true,
          "heartbeat": "Device heartbeat status retrieved."
      }
      ```

3. **Get Device Address**
    - **Endpoint**: `/api/address`
    - **Method**: GET
    - **Description**: Retrieves the address information of a device.
    - **Response Example**:
      ```json
      {
          "success": true,
          "address": "Device address retrieved."
      }
      ```

4. **Get Latest Check-in**
    - **Endpoint**: `/api/latest_checkin`
    - **Method**: GET
    - **Description**: Returns the most recent check-in data.
    - **Response Example**:
      ```json
      {
          "success": true,
          "latest_checkin": { "UserID": "1", "CheckInTime": "2024-11-06 08:00" }
      }
      ```

5. **Get Latest Connection**
    - **Endpoint**: `/api/latest_connection`
    - **Method**: GET
    - **Description**: Retrieves the latest connection status updates.
    - **Response Example**:
      ```json
      {
          "success": true,
          "latest_connection": { "deviceId": "ESP32-001", "status": "connected" }
      }
      ```

6. **Get Latest Temperature**
    - **Endpoint**: `/api/latest_temperature`
    - **Method**: GET
    - **Description**: Fetches the latest temperature and humidity reading.
    - **Response Example**:
      ```json
      {
          "success": true,
          "temperature": "23.5",
          "humidity": "60"
      }
      ```

7. **Get Temperature and Humidity Logs**
    - **Endpoint**: `/api/temperature_humidity`
    - **Method**: GET
    - **Description**: Retrieves the last 60 temperature and humidity records.
    - **Response Example**:
      ```json
      {
          "success": true,
          "data": [
              { "timestamp": "2024-11-05 14:00", "temperature": "23.5", "humidity": "60" },
              { "timestamp": "2024-11-05 13:00", "temperature": "22.8", "humidity": "58" }
          ]
      }
      ```

8. **Get Leaderboard**
    - **Endpoint**: `/api/leaderboard`
    - **Method**: GET
    - **Description**: Provides a leaderboard based on user session data.
    - **Response Example**:
      ```json
      {
          "success": true,
          "leaderboard": [
              { "UserID": "1", "name": "Alice", "totalPitchers": "5" },
              { "UserID": "2", "name": "Bob", "totalPitchers": "4" }
          ]
      }
      ```

9. **Get All Sessions**
    - **Endpoint**: `/api/session`
    - **Method**: GET
    - **Description**: Lists all session entries with details for each user.
    - **Response Example**:
      ```json
      {
          "success": true,
          "sessions": [
              { "SessionID": "1", "UserID": "1", "CheckInTime": "08:00", "CheckOutTime": "17:00" }
          ]
      }
      ```

10. **Get Time Registration Data**
    - **Endpoint**: `/api/time_registration`
    - **Method**: GET
    - **Description**: Retrieves time registration data for users.
    - **Response Example**:
      ```json
      {
          "success": true,
          "registrations": [
              { "UserID": "1", "name": "Alice", "role": "admin" }
          ]
      }
      ```

11. **Get Users**
    - **Endpoint**: `/api/users`
    - **Method**: GET
    - **Description**: Lists all users with role and RFID data.
    - **Response Example**:
      ```json
      {
          "success": true,
          "users": [
              { "UserID": "1", "name": "Alice", "role": "admin", "RFID_Tag": "123456" }
          ]
      }
      ```

12. **Get Cumulative Statistics**
    - **Endpoint**: `/api/cumulative_statistics`
    - **Method**: GET
    - **Description**: Provides cumulative statistics on sessions and users.
    - **Response Example**:
      ```json
      {
          "success": true,
          "cumulative_data": { "total_sessions": "10", "total_hours": "50" }
      }
      ```

13. **Get Pitcher Statistics**
    - **Endpoint**: `/api/pitcher_statistics`
    - **Method**: GET
    - **Description**: Provides statistics about pitcher consumption, including total pitchers, money spent, and top consumers.
    - **Response Example**:
      ```json
      {
          "success": true,
          "pitcher_data": {
              "total_pitchers": "100",
              "total_money_spent": "1400",
              "pitchers_per_session": "2.5",
              "most_pitchers_session_date": "2024-11-01",
              "most_pitchers_in_session": "5"
          }
      }
      ```

14. **Get Pitcher Consumption per User**
    - **Endpoint**: `/api/pitcher_consumption`
    - **Method**: GET
    - **Description**: Retrieves consumption data showing pitchers consumed per user.
    - **Response Example**:
      ```json
      {
          "success": true,
          "pitcher_consumption": [
              { "name": "Alice", "total_pitchers": "10", "total_sessions": "5" },
              { "name": "Bob", "total_pitchers": "8", "total_sessions": "4" }
          ]
      }
      ```

---

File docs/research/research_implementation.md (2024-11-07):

# Research implementation 
<!-- Adding braille to device -->

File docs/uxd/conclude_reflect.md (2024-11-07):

# Conclude & Reflect
## Conclude





## Reflect
The DHT11 burnt through


The original casing was too small I needed a pcb

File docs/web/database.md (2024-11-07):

# Database

I have created an ERD using dbdiagram that can create visuals from text input, both text input and visuals are added below.

## ERD
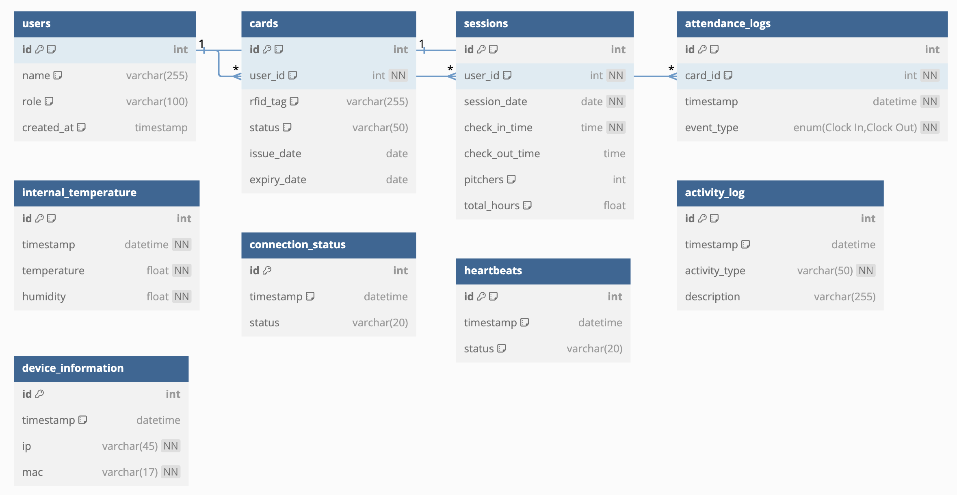
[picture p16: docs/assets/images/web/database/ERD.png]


````mermaid
Table users {
  id int [primary key, note: 'User ID']
  name varchar(255) [note: 'User name']
  role varchar(100) [note: 'User role (e.g., Employee, Manager)']
  created_at timestamp [default: `now()`]
}

Table cards {
  id int [primary key, note: 'Card ID']
  user_id int [not null, ref: > users.id, note: 'Associated user ID']
  rfid_tag varchar(255) [unique, note: 'RFID tag']
  status varchar(50) [default: 'Active']
  issue_date date
  expiry_date date
}

Table sessions {
  id int [primary key, note: 'Session ID']
  user_id int [not null, ref: > users.id, note: 'Associated user ID']
  session_date date [not null]
  check_in_time time [not null]
  check_out_time time
  pitchers int [default: 0, note: 'Pitcher count']
  total_hours float [note: 'Calculated total hours']
}

Table attendance_logs {
  id int [primary key, note: 'Log ID']
  card_id int [not null, ref: > cards.id, note: 'Associated card ID']
  timestamp datetime [not null]
  event_type enum('Clock In', 'Clock Out') [not null]
}

Table internal_temperature {
  id int [primary key, note: 'Temperature Log ID']
  timestamp datetime [not null]
  temperature float [not null]
  humidity float [not null]
}

Table connection_status {
  id int [primary key]
  timestamp datetime [default: `CURRENT_TIMESTAMP`]
  status varchar(20)
}

Table heartbeats {
  id int [primary key, note: 'Heartbeat ID']
  timestamp datetime [default: `CURRENT_TIMESTAMP`]
  status varchar(20) [default: 'Active']
}

Table activity_log {
  id int [primary key, note: 'Activity Log ID']
  timestamp datetime [default: `CURRENT_TIMESTAMP`]
  activity_type varchar(50) [not null]
  description varchar(255)
}

Table device_information {
  id int [primary key]
  timestamp datetime [default: `CURRENT_TIMESTAMP`]
  ip varchar(45) [not null]
  mac varchar(17) [not null]
}
````

## EER
Using mysqldatabase I've created an EER with all the proper fields, relations and specifiers

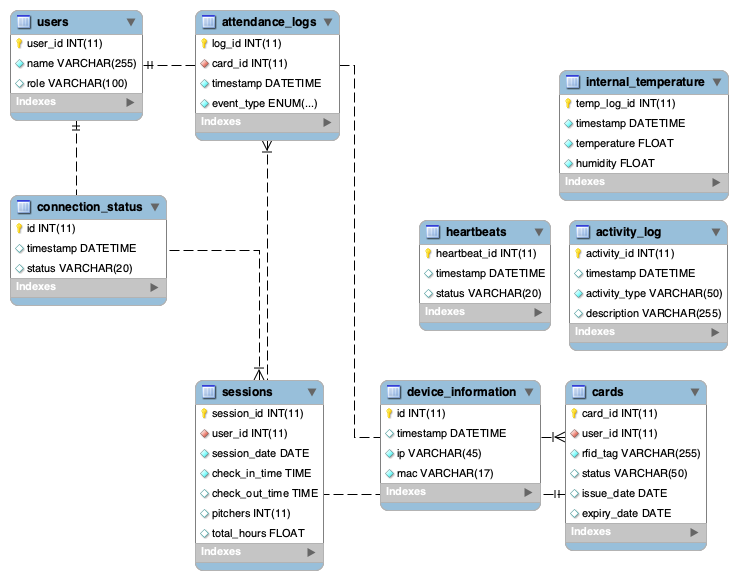
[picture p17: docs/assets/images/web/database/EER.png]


## SQL
From the previously made EER I can generate a mysql querry to create the database.

```` mysql
CREATE DATABASE smart_time_registration;
USE smart_time_registration;

CREATE TABLE users (
    user_id INT AUTO_INCREMENT PRIMARY KEY,
    name VARCHAR(255) NOT NULL,
    role VARCHAR(100)
);

CREATE TABLE cards (
    card_id INT AUTO_INCREMENT PRIMARY KEY,
    user_id INT NOT NULL,
    rfid_tag VARCHAR(255) UNIQUE NOT NULL,
    status VARCHAR(50) DEFAULT 'Active',
    issue_date DATE,
    expiry_date DATE,
    FOREIGN KEY (user_id) REFERENCES users(user_id)
        ON DELETE CASCADE
        ON UPDATE CASCADE
);

CREATE TABLE sessions (
    session_id INT AUTO_INCREMENT PRIMARY KEY,
    user_id INT NOT NULL,
    session_date DATE NOT NULL,
    check_in_time TIME NOT NULL,
    check_out_time TIME,
    pitchers INT DEFAULT 0,
    total_hours FLOAT GENERATED ALWAYS AS (
        TIMESTAMPDIFF(SECOND, CONCAT(session_date, ' ', check_in_time), CONCAT(session_date, ' ', check_out_time)) / 3600
    ) STORED,
    FOREIGN KEY (user_id) REFERENCES users(user_id)
        ON DELETE CASCADE
        ON UPDATE CASCADE
);

CREATE TABLE attendance_logs (
    log_id INT AUTO_INCREMENT PRIMARY KEY,
    card_id INT NOT NULL,
    timestamp DATETIME NOT NULL,
    event_type ENUM('Clock In', 'Clock Out') NOT NULL,
    FOREIGN KEY (card_id) REFERENCES cards(card_id)
        ON DELETE CASCADE
        ON UPDATE CASCADE
);

CREATE TABLE internal_temperature (
    temp_log_id INT AUTO_INCREMENT PRIMARY KEY,
    timestamp DATETIME NOT NULL,
    temperature FLOAT NOT NULL,
    humidity FLOAT NOT NULL
);

CREATE TABLE connection_status (
    id INT AUTO_INCREMENT PRIMARY KEY,
    timestamp DATETIME DEFAULT CURRENT_TIMESTAMP,
    status VARCHAR(20)
);

CREATE TABLE heartbeats (
    heartbeat_id INT AUTO_INCREMENT PRIMARY KEY,
    timestamp DATETIME DEFAULT CURRENT_TIMESTAMP,
    status VARCHAR(20) DEFAULT 'Active'
);

CREATE TABLE activity_log (
    activity_id INT AUTO_INCREMENT PRIMARY KEY,
    timestamp DATETIME DEFAULT CURRENT_TIMESTAMP,
    activity_type VARCHAR(50) NOT NULL,
    description VARCHAR(255)
);

CREATE TABLE device_information (
    id INT AUTO_INCREMENT PRIMARY KEY,
    timestamp DATETIME DEFAULT CURRENT_TIMESTAMP,
    ip VARCHAR(45) NOT NULL,
    mac VARCHAR(17) NOT NULL
);
````

---

### Step-by-Step Guide for Using the SQL Script

1. **Clone the Repository:** Begin by cloning the GitLab project repository to your local machine.
   ```bash
   git clone git@gitlab.fdmci.hva.nl:IoT/2024-2025-semester-1/individual-project/zuuliiyiizoo76.git
   ```
   
2. **Access the SQL Script:** Navigate to the SQL script file in the project directory.
   ```bash
   cd zuuliiyiizoo7/web/php/
   ```

3. **Database Creation:** Open your MySQL client, then run the SQL script to set up the database.
   ```sql
   SOURCE smart_time_registration.sql;
   ```

4. **Verify Database Setup:** Check that all tables are created successfully by listing the tables in the `smart_time_registration` database:
   ```sql
   USE smart_time_registration;
   SHOW TABLES;
   ```

---

### Accessing the SQL Script

You can find the SQL script in the GitLab project repository at the following link:

[SQL Script on GitLab](https://gitlab.fdmci.hva.nl/IoT/2024-2025-semester-1/individual-project/zuuliiyiizoo76/-/blob/main/web/smart_time_registration.sql)

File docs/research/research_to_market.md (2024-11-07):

# Research to market

### Introduction

Imagine a group of friends enjoying a beer night together. One of them, Alex, is visually impaired. While his friends use the Beertracker HUB effortlessly to track their beer consumption, Alex faces significant challenges in interacting with the system. Current designs of Beertracker HUB do not account for individuals with visual impairments, which leaves people like Alex excluded from this shared experience. With accessibility becoming an increasingly important aspect of product design, addressing these challenges not only helps improve inclusion but also broadens the user base. Enhancing accessibility for visually impaired individuals is a meaningful pursuit, both from an ethical and market perspective, as it empowers a wider audience to fully engage with products. This research focuses on enhancing the accessibility of Beertracker HUB for blind users by proposing and evaluating practical improvements to the interface and interaction model.

### Research Question and Sub-Questions

**Main Research Question:** How can the Beertracker HUB be redesigned to make it more accessible for visually impaired users?

**Sub-Questions:**

1. What are the specific challenges faced by visually impaired users when interacting with the current Beertracker HUB interface?
2. What are the best practices for designing accessible interfaces for blind users?
3. How can audio feedback, tactile components, a braille display, and voice activation be integrated into Beertracker HUB to enhance usability?
4. What technologies are available to support accessibility in embedded and physical systems?

### Research Methodology

To answer the research question and sub-questions, a mixed-method approach was used:

1. **User Interviews**: Interviews were conducted with visually impaired individuals to identify the main challenges they face while using Beertracker HUB and similar products. These interviews aimed to gain qualitative insights into user needs, preferences, and pain points.
2. **Accessibility Testing**: The current Beertracker HUB was tested by both visually impaired and sighted users. Accessibility experts were also consulted to evaluate the system and provide detailed feedback on usability issues.
3. **Literature Review**: A review of existing literature on accessibility design, specifically for embedded systems and smart hubs, was performed. This helped identify best practices and successful design principles.
4. **Prototype Testing**: A prototype with proposed modifications was developed and tested by users to evaluate the effectiveness of these changes. The prototype included audio feedback, a braille display, and voice activation features to assist navigation.

### Findings and Evidence

The research revealed several key challenges:

- **Interface Complexity**: The current system heavily relies on visual cues, making it challenging for visually impaired users to interact with.
- **Lack of Feedback**: The Beertracker HUB lacks sufficient auditory or tactile feedback, which limits its accessibility for users who cannot rely on visual interaction.
- **User-Centered Improvements**: From user interviews, it became clear that blind users preferred clear, immediate auditory feedback when interacting with the system. Some users also suggested adding a braille display for tactile guidance and voice activation for hands-free interaction.

To address these challenges, a prototype incorporating the following features was developed:

- **Audio Feedback System**: Audio prompts were added to guide users through the interaction process, such as confirming actions like beer logging or navigating through menu options.
- **Tactile Buttons and Braille Display**: Physical buttons with braille labels were added, along with a braille display to provide real-time information, enabling users to perform basic functions without needing to see the screen.
- **Voice Activation**: Voice commands were integrated into the system, allowing users to navigate menus and log beers hands-free, providing an additional layer of accessibility.

User testing of the improved prototype showed a significant increase in satisfaction and ease of use among visually impaired participants. The inclusion of auditory feedback, tactile components, a braille display, and voice activation made the system much more user-friendly and intuitive.

### Reactions to Different Buzzer Sounds

As part of the accessibility improvements, different buzzer sounds were tested to determine user reactions and preferences. The findings showed that the tone and type of buzzer sound could convey different types of feedback effectively:

- **High-Pitched Tone for Positive Actions**: A high-pitched, short buzzer sound was used to indicate positive actions, such as successfully logging a beer. Users responded positively to this sound, as it provided an immediate and clear indication of success.
- **Low-Pitched Tone for Errors**: A low-pitched, longer buzzer sound was used to indicate errors or invalid actions. This type of feedback helped users quickly understand when something had gone wrong, allowing them to adjust their actions accordingly.
- **Rising Tone for System Ready**: A rising tone sequence was used to indicate that the system was ready for input. This sound was found to be effective in signaling users to proceed with their actions.
- **Falling Tone for Session End**: A falling tone sequence was used to indicate the end of a session or when the user had completed their interaction. This provided a clear and satisfying conclusion to the interaction.

The use of different buzzer sounds, combined with other feedback mechanisms, greatly enhanced the overall user experience by providing non-visual cues that were easy to interpret. This multi-modal approach helped ensure that blind users received clear and actionable feedback during their interaction with the Beertracker HUB.

### Proposed Improvements and Implementation

Based on the findings, the following improvements were proposed and documented on the portfolio website:

- **Audio Feedback Integration**: A module providing voice feedback for key actions, enabling blind users to understand what action has been performed.
- **Braille-Enhanced Physical Interface and Display**: Incorporating braille labels for all key buttons and a braille display for real-time system information, making the system more accessible.
- **Voice Activation Feature**: Adding voice commands to enable users to navigate the interface and log actions without the need for physical input.
- **Simplified Navigation**: Reducing the complexity of the menu to ensure that visually impaired users can quickly learn and use the system effectively.
- **Buzzer Feedback System**: Incorporating different buzzer tones to indicate positive actions, errors, readiness, and session end, providing users with immediate auditory cues that enhance interaction.

The implementation of these features is documented with code explanations, images of the modified interface, and video demonstrations showing blind users interacting with the improved prototype.

### Conclusion

This research addressed the main research question by demonstrating how the Beertracker HUB could be made more accessible for visually impaired users. The introduction of audio feedback, tactile components, a braille display, voice activation, and differentiated buzzer sounds significantly improved the usability of the system. Key findings showed that providing multiple forms of feedback—auditory, tactile, and voice—enabled a much more inclusive experience for blind users.

**Recommendations**:

- Future improvements could include developing a mobile app that interfaces with Beertracker HUB, providing personalized voice control and further enhancing accessibility.
- Additional research could explore the use of machine learning to predict user actions and provide anticipatory assistance, further reducing barriers for visually impaired users.

**References**: The research included a mix of up-to-date articles and books on accessibility design, case studies on accessible embedded systems, and guidelines from trusted organizations like the World Wide Web Consortium (W3C). Referencing was done consistently in APA style throughout the documentation.

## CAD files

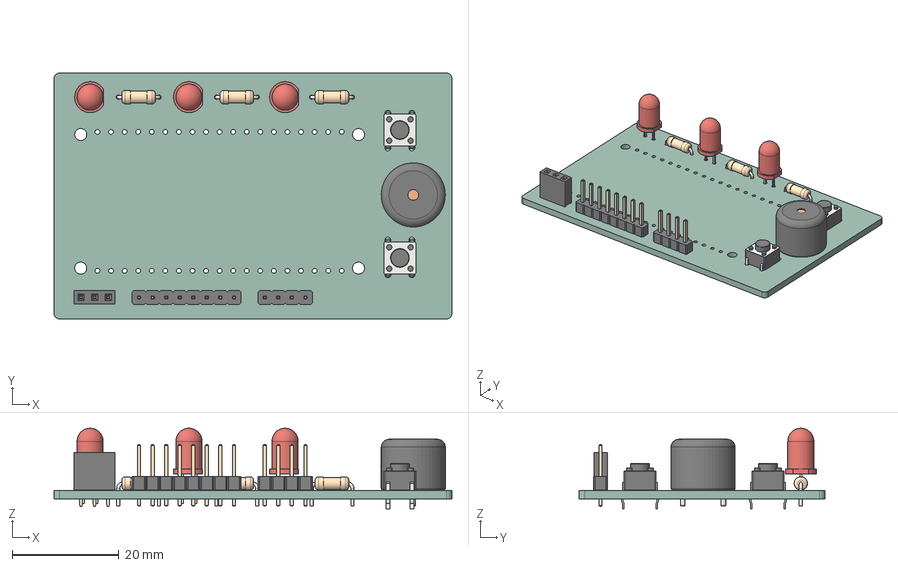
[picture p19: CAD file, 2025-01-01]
Beertracker HUB PCB/Beertracker HUB PCB.step
74.5 x 46.0 x 15.1 mm
R_Axial_DIN0207_L63mm_D25mm_P762mm_Horizontal x 3
LED_D5.0mm x 3
SW_PUSH_6mm_h5mm x 2
Buzzer_12x95RM76
PinHeader_1x08_P254mm_Vertical
PinSocket_1x03_P254mm_Vertical
PinHeader_1x04_P254mm_Vertical
Beertracker HUB PCB_PCB

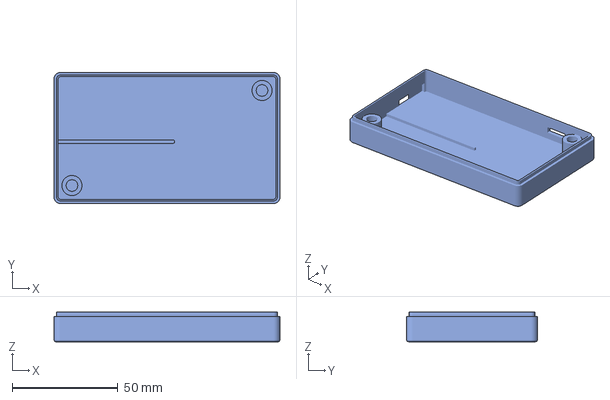
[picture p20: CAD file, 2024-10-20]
cad/back-plate/back-plate v0.15.3mf
107.0 x 62.0 x 14.0 mm

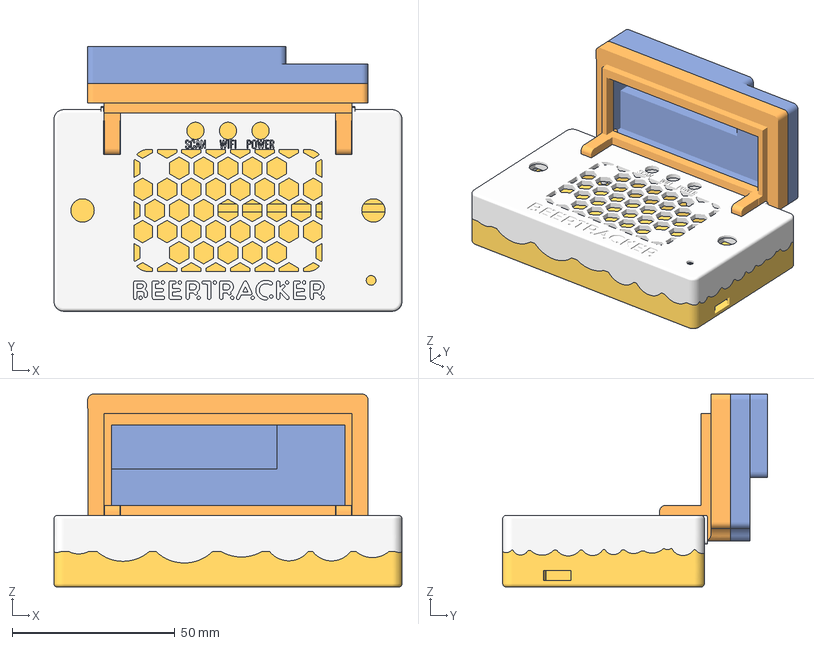
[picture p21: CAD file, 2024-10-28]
cad/Beertracker HUB Housing V1.3.3mf
107.0 x 81.3 x 59.3 mm
LCD-back-plate
LCD-front-plate
front-plate legit
back-plate legit

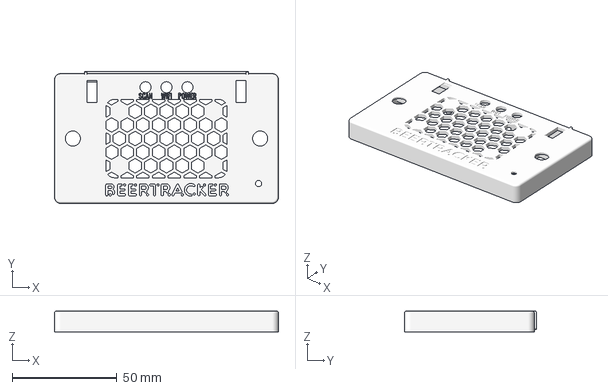
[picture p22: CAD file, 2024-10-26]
cad/front-plate/front-plate v0.16.3mf
107.0 x 63.0 x 10.0 mm

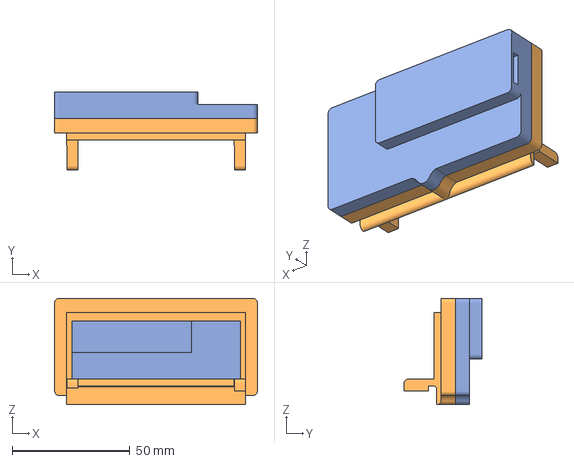
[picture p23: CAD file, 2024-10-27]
cad/lcd-plate/LCD-plate V0.7.3mf
86.3 x 33.1 x 45.1 mm
LCD-back-plate
LCD-front-plate

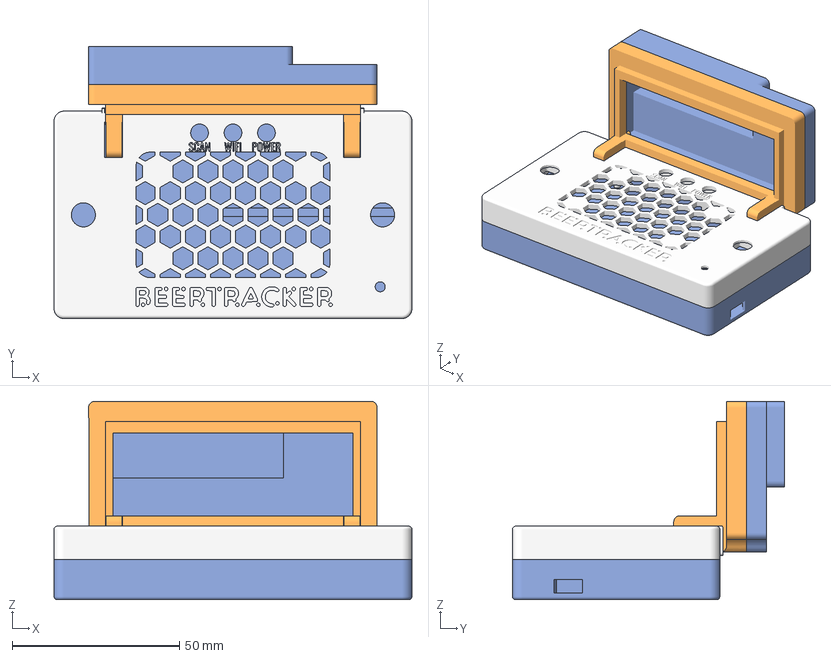
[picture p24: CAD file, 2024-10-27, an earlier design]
cad/Beertracker HUB Housing V1.2.3mf
107.0 x 81.3 x 59.3 mm
front-plate
back-plate
LCD-front-plate
LCD-back-plate

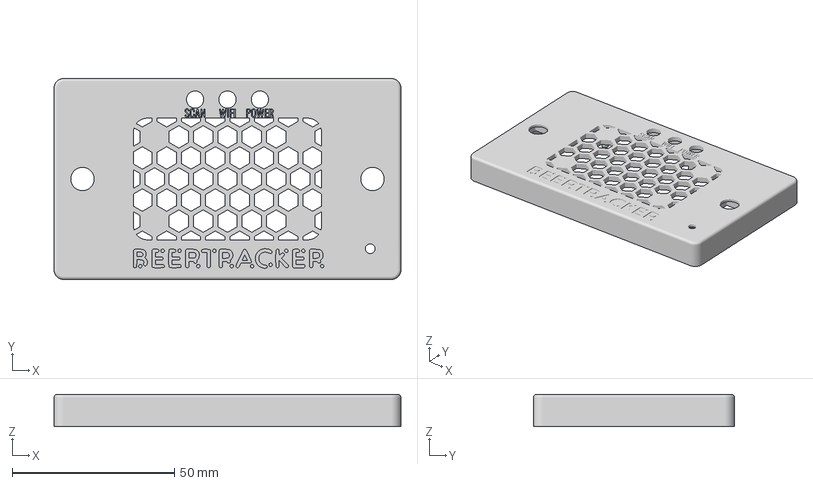
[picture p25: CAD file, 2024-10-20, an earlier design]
cad/front-plate/front-plate v0.15.3mf
107.0 x 62.0 x 10.0 mm

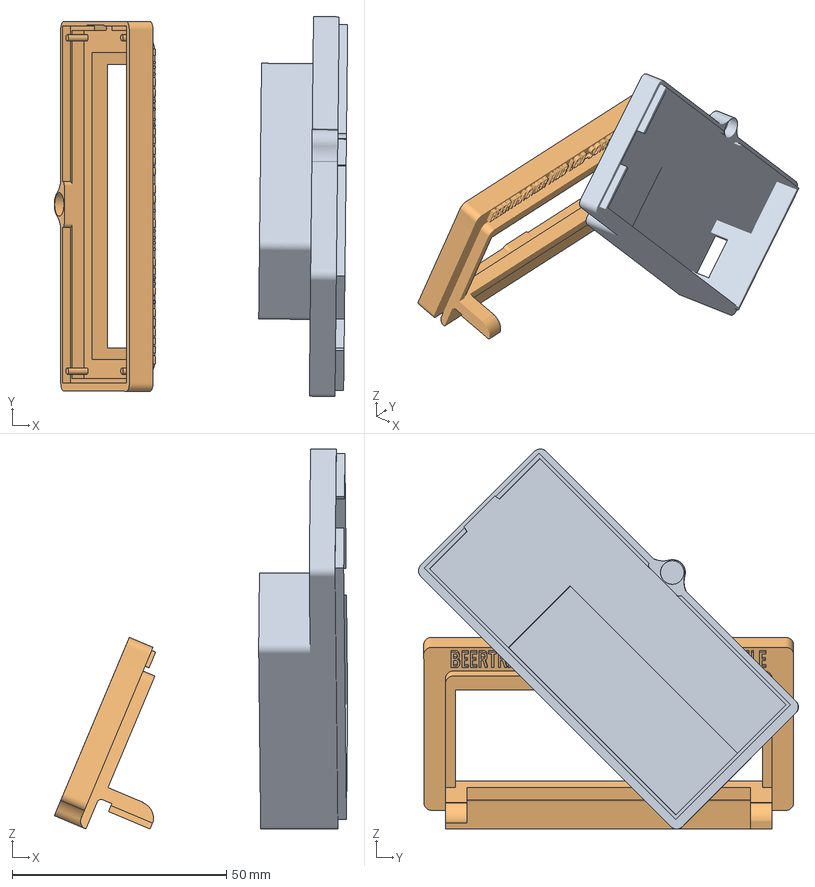
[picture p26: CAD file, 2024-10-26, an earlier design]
cad/lcd-plate/LCD-plate V0.6.3mf
68.4 x 88.6 x 88.6 mm
LCD-back-plate
LCD-front-plate

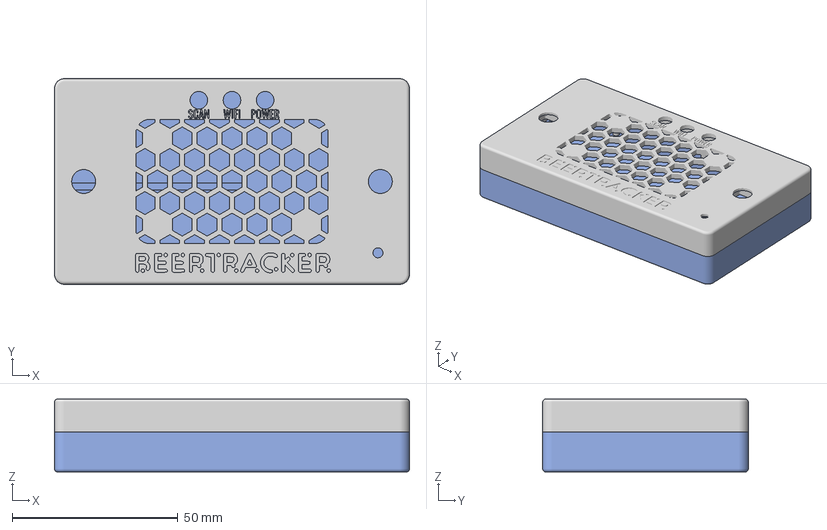
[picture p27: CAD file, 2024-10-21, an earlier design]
cad/Beertracker HUB Housing V1.0.3mf
107.0 x 62.0 x 22.0 mm
back-plate
front-plate

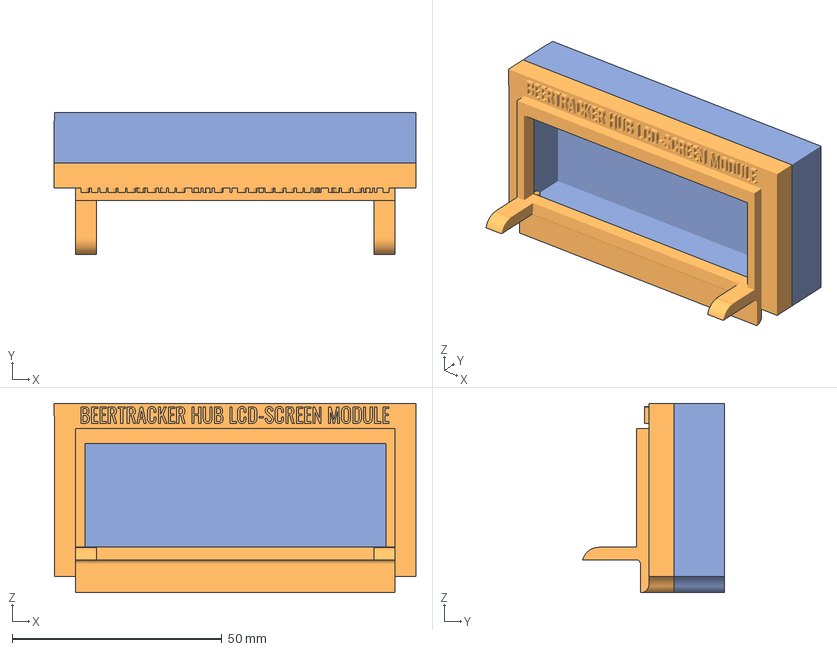
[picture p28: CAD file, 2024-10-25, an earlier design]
cad/lcd-plate/LCD-plate v0.5.3mf
86.3 x 33.8 x 45.1 mm
LCD-back-plate
LCD-front-plate

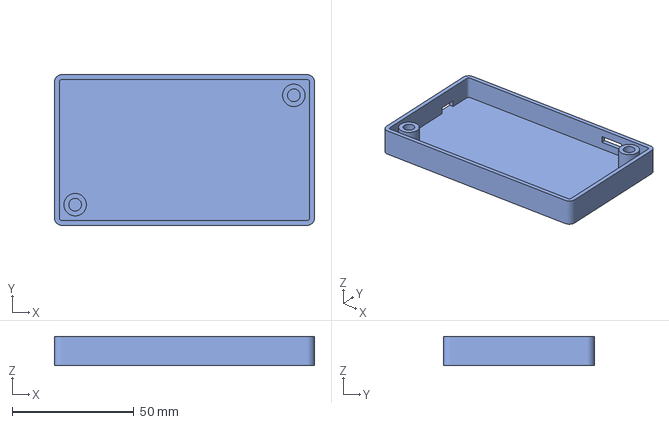
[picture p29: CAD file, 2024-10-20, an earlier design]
cad/back-plate/back-plate v0.12.3mf
107.0 x 62.0 x 12.0 mm

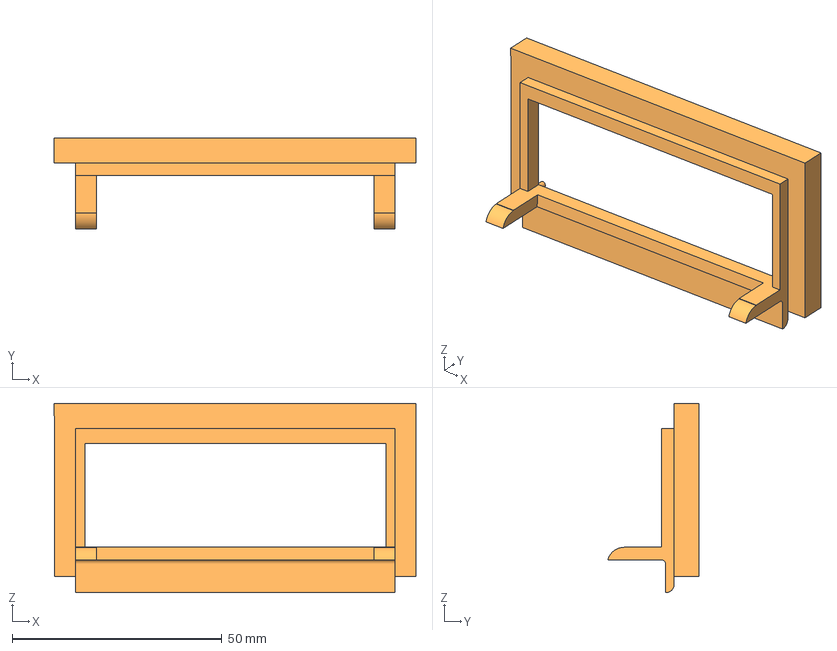
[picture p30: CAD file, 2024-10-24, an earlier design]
cad/lcd-plate/LCD-plate V0.4.3mf
86.3 x 21.8 x 45.1 mm

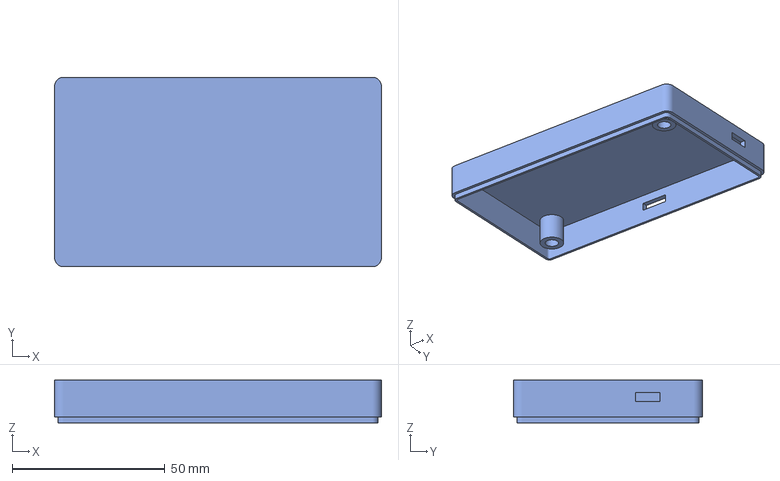
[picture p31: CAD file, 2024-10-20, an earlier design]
cad/back-plate/back-plate v0.11.3mf
107.0 x 62.0 x 14.0 mm

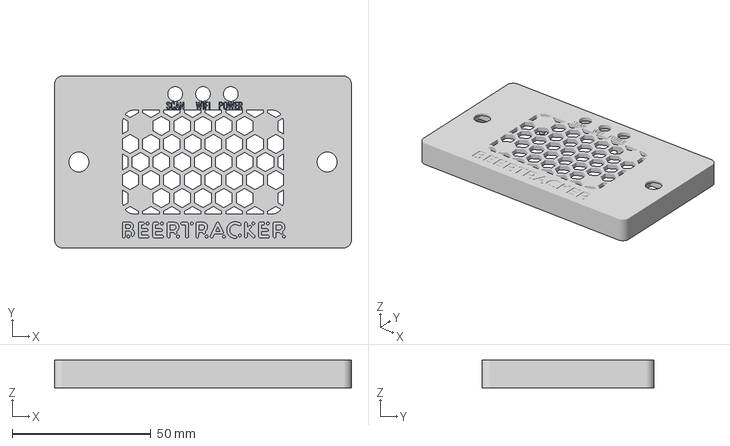
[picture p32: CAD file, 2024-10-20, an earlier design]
cad/front-plate/front-plate v0.12.3mf
107.0 x 62.0 x 10.0 mm

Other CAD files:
cad/back-plate/back-plate v0.14.3mf
cad/back-plate/back-plate v0.13.3mf
cad/front-plate/front-plate v0.14.3mf
cad/front-plate/front-plate v0.13.3mf
cad/back-plate/back-plate V0.9.3mf
cad/back-plate/back-plate v0.10.3mf
cad/front-plate/front-plate V0.9.3mf
cad/front-plate/front-plate v0.1.3mf
cad/front-plate/front-plate v0.10.3mf
cad/front-plate/front-plate v0.11.3mf
cad/front-plate/front-plate v0.2.3mf
cad/front-plate/front-plate v0.3.3mf
cad/front-plate/front-plate v0.4.3mf
cad/front-plate/front-plate v0.5.3mf
cad/front-plate/front-plate v0.6.3mf
cad/front-plate/front-plate v0.7.3mf
cad/front-plate/front-plate v0.8.3mf
cad/lcd-plate/LCD-plate V0.3.3mf
cad/lcd-plate/LCD-plate v0.1.3mf
cad/lcd-plate/LCD-plate v0.2.3mf

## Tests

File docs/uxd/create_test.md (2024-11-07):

# Create & Test

## Test Details

- **Date:** 06-11-2024
- **Tester Name:** Lucas
- **Test Conducted By:** Lars
- **Test Location:** HvA

---

## Physical Check-In/Out Test

### Goal:
Test the process of checking in and out with the physical BeerTracker hub.

### Instructions:
1. Approach the BeerTracker hub.
2. Follow the instructions provided to check in and check out.
3. Record observations about ease of use, clarity, and speed.

### User Feedback

- **Was the process easy to understand?** 
  - [x] Yes
  - [ ] No
- **Was the check-in/check-out process intuitive?** 
  - [x] Yes
  - [ ] No
- **Comments on the physical item usability (e.g., button placement, display readability, etc.):** 
  - the button are loose

#### Suggestions for Improvement:
- make the menu selector faster

---

## Website Interaction Test

### Goal:
Test the account creation and UID update processes on the BeerTracker website.

### Instructions:
1. Navigate to the BeerTracker website.
2. Register a new account.
3. Update the UID for the newly created account.
4. Record observations about ease of navigation, clarity of instructions, and speed.

### User Feedback

- **Was the account creation process straightforward?** 
  - [x] Yes
  - [ ] No
- **Was the UID update process easy to locate and complete?** 
  - [x] Yes
  - [ ] No
- **Comments on website usability (e.g., button placement, navigation, form clarity):** 
  - the tabs are clear

#### Suggestions for Improvement:
- make it so the topbar goes back to dashboard

---

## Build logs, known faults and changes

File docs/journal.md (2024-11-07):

# Learning journal

## Week 1
In week one I tried to tackle a bunch of different aspects of the project. I choose the blueprint **Smart Time Registration.** and started planning out what I needed to create for this project. I have been keeping track of my tasks and ideas in Trello. 

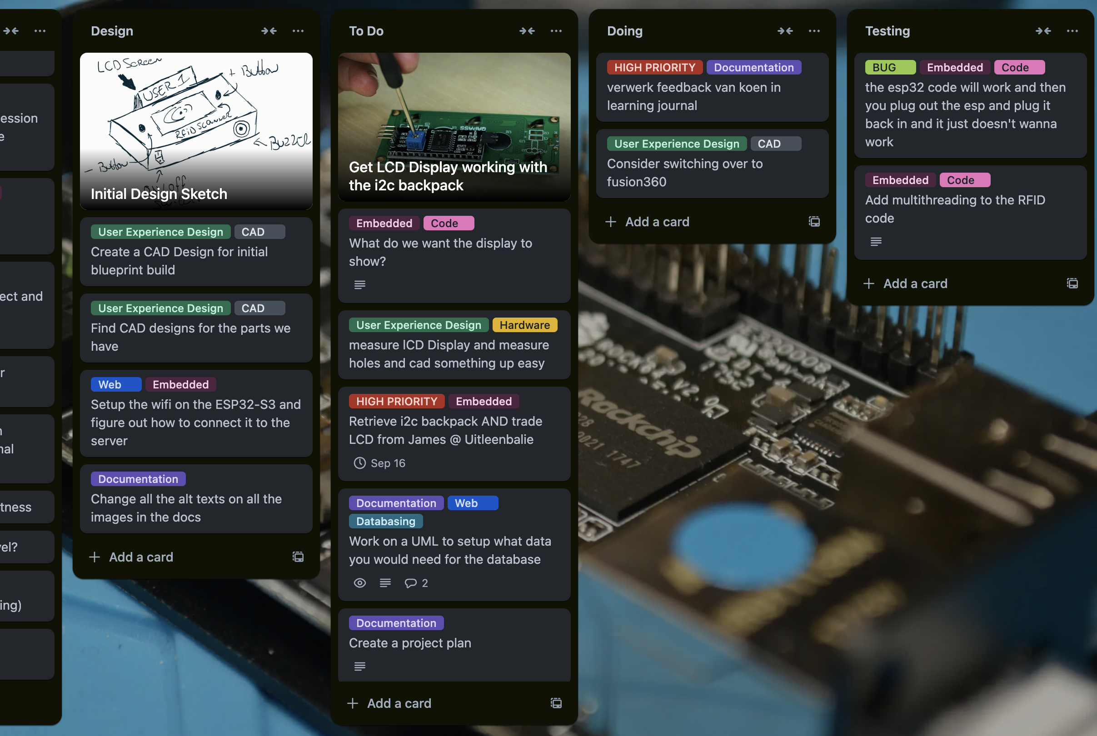
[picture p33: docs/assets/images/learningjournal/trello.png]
Trello Board with tasks


I setup the project using Docker, created a venv for python so I could run my portfolio website locally and started working on the *Embedded* part of the project first.

I started creating my circuit in Fritzing and using the WeMOS which I later switched over to the ESP32-S3 after seeing that for the additional sensors and outputs I wanted to add still I would not have the available pins required on the WeMOS so I moved over to the ESP32.

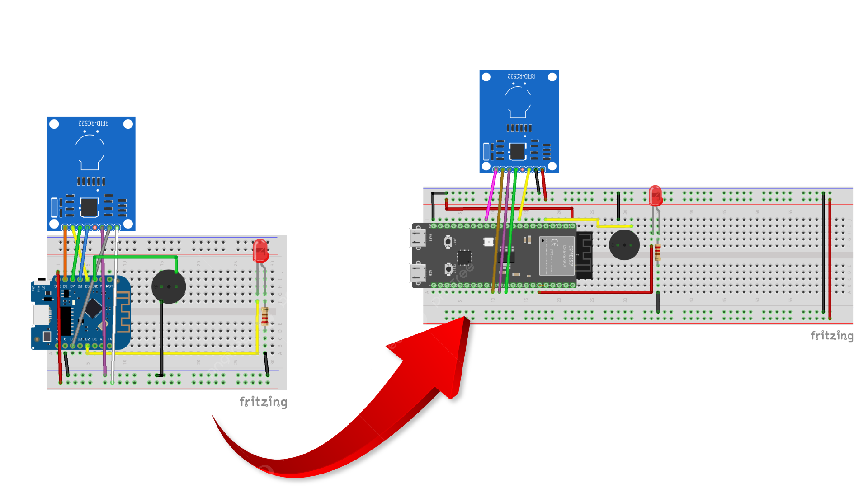
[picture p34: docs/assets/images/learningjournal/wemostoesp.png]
Fritzing diagrams moving from WeMOS to ESP32


I then built the circuit on my breadboard and wrote the code for it, and I was able to read the UID of the HvA passes.

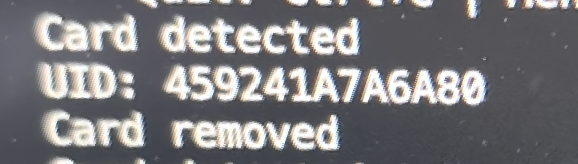
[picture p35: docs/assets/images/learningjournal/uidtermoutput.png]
Output of the serial monitor


I then moved my focus to writing the required documentation for the work I've done and shifted my focus on two other aspects of the project. The website and the User Experience Design. For the website I wanted to start with looking into how to make the database required for project and started making an ERD. This ERD still has to be worked on further and implemented. For User Experience Design I wanted to start learning how to use CAD and how to adapt CAD Designs to existing components.

I took an LCD to start learning this, I looked up the datasheet where I was able to find the dimensions of the device and started sketching that out in OnShape where I could then design an enclosement around it.

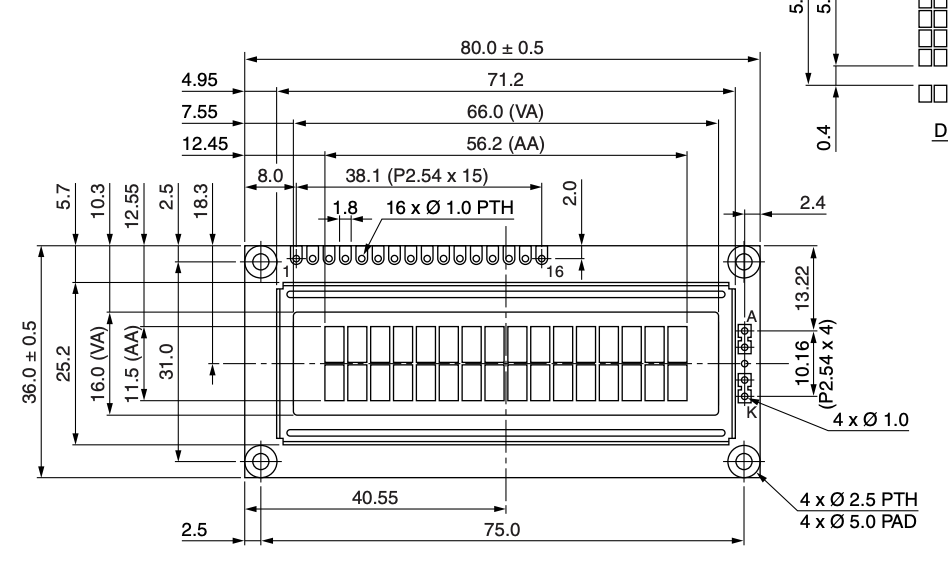
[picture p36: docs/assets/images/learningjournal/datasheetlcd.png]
Datasheet of the LCD

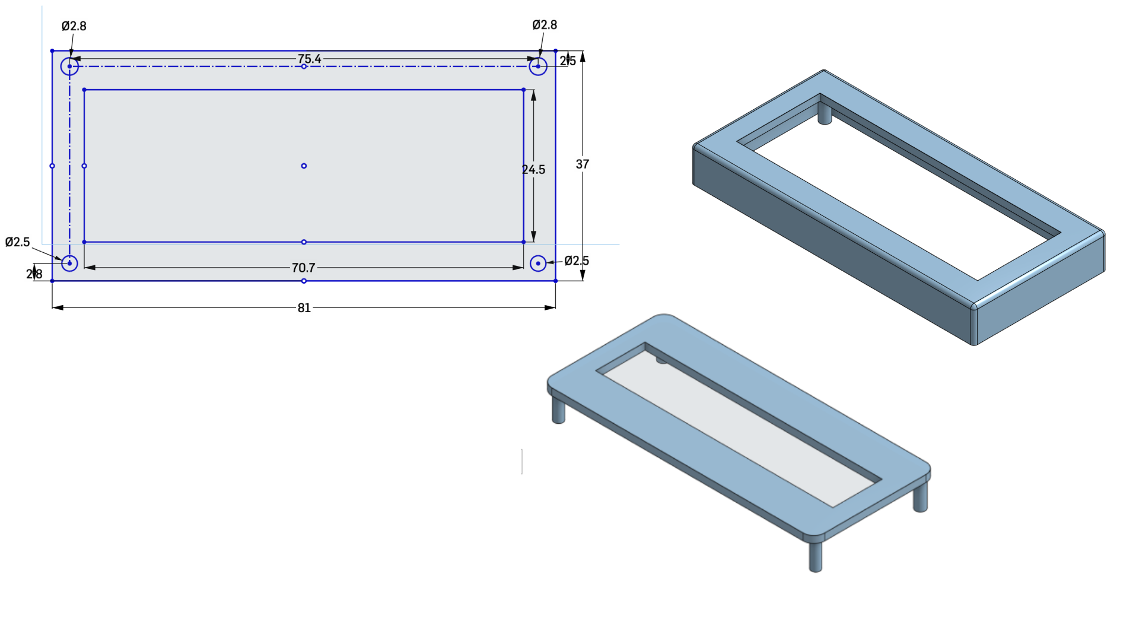
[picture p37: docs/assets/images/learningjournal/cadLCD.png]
Cadding of the enclosement


<br>

### Feedback
**🧰 System Requirements** (solved)

**Reviewer:** Koen Lammers

**Feedback:** It looks like a realy good page for your system requirement, realy detailed and covers all the parts of your system. Be sure to check them to yes when you finish one and also add the description with code on how you solved the problem!

**Takeaway:** I should often revisit this page and see whether I've finished a requirement and properly document it when I do.

<br>

## Performance Review Week 1
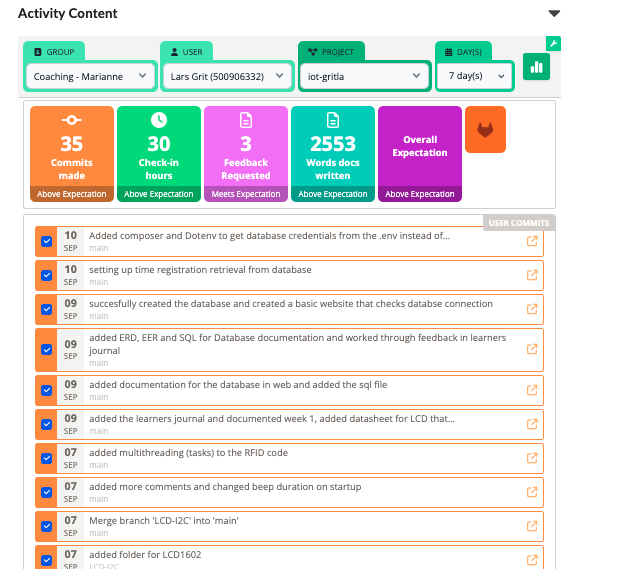
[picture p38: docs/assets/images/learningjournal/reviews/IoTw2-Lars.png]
performance review


<br>

---

## Week 2
Week two started with writing out my learning journal and figuring out how to tackle the feedback and also writing out a project plan with weekly goals and aspirations. This week was a lot of work building the website and making the required steps to achieve it. I started with the database where I used UML to figure out what data was required of this project to be in a database and sketched out an ERD. When that looked good I started making the EERD in *MySQL Database* from which I could generate my database.

EER of website

With the database up and running it was time to start working on the website, this had to be done with the PHP, JS and HTML + CSS for styling. Using PHP I could make query's and calls to my database and encode it withing JSON which JS can fetch and work out it's information with it. I created a connection check that checks if the website has connection to the database and created a table which prints out all the users and their associated pass UID. 

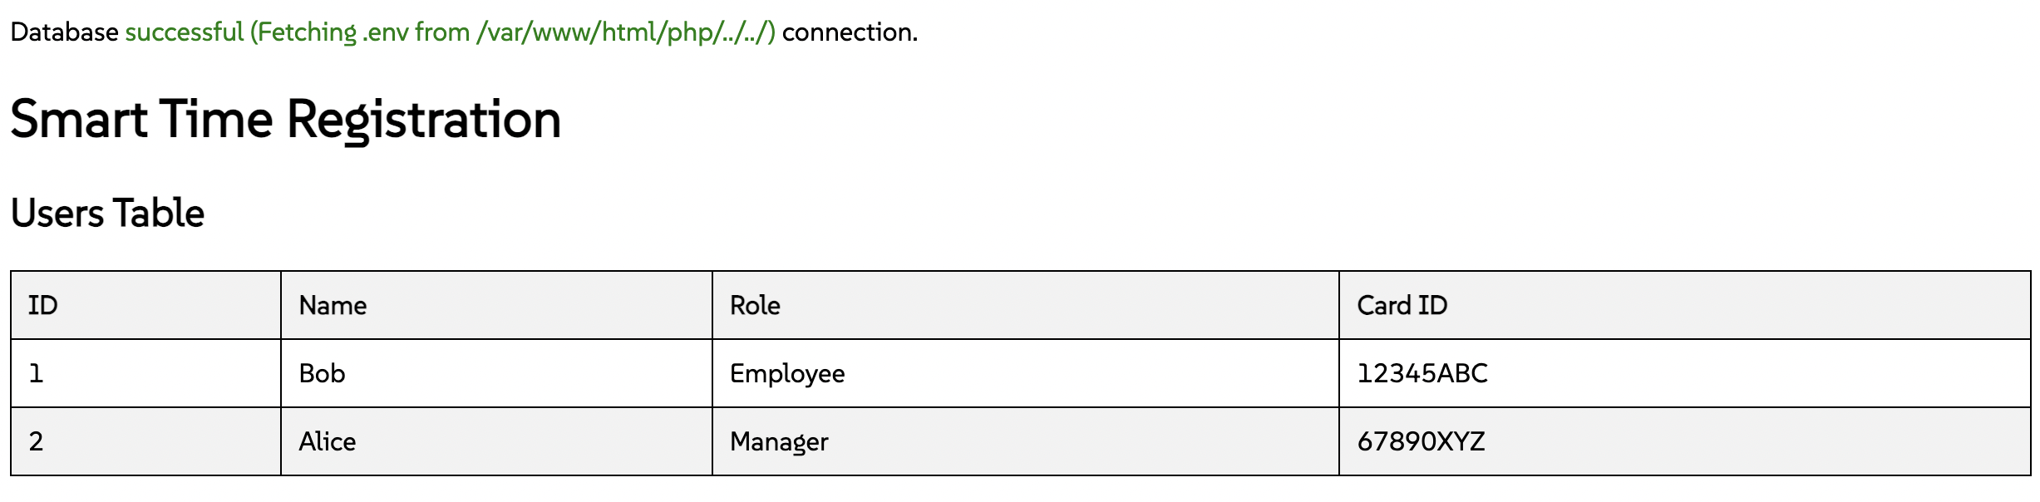
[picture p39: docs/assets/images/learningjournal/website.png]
Screenshot of the website


To secure the website and database I didn't want to have my credentials hard coded into the websites code so I had to learn how to expand my docker to install composer from which I could then install php packages like DOTENV which made it possible for me to store my database credentials in an only local file so other people could not have access to it.

Having created a solid basis for the website I expanded my embedded part by adding a new output, the lcd screen. Getting it to work was a lot of trial and error. I used the i2c backpack which I had to solder unto the lcd screen itself. Using this I significantly lowered the amount of pins required to get the LCD display to work. My biggest struggle was to get the lcd display sufficiently powered since it requires 5v and the esp32 only has 3.3v output pins. This required me to use the 9v battery included in the IoT kit but not wanting to overpower the display I had to come to a solution to get the power from 9v to 5v for which I used a mini DCDC converter which gave me an output of 5v. 

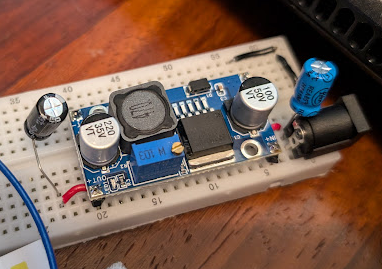
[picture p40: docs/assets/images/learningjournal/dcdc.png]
dcdc setup


Lastly I have gotten my esp32 connected to the wifi using a wifi manager which makes it so I again don't have any potential important info saved in the code. I sketched out some more designs for my device and thought of fun additions and created the basis for my API. Which will handle the data calls from device to device.

second sketch of the device

<br>

### Feedback
**🧰 Technical Documentations** (unsolved)

**Reviewer:** Melvin Moes

**Feedback:** Looks good maybe add the prices to the component list. This way you could show a total price of making your system.

**Takeaway:** I should add a column with prices, even though Melvin did not mention it I should change the BOM to places where I can purchase one from instead of where I got it. I should remove the HvA as supplier for example.

<br>

**🧰 Technical Documentations** (unsolved)

**Reviewer:** Koen Lammers

**Feedback:** Be sure to add the url to the store pages! the rest looks clean and good!

**Takeaway:** I should make sure to add links to the suppliers in the BOM to redirect them to the product.

<br>

**🌐 Database** (unsolved)

**Reviewer:** Melvin Moes

**Feedback:** Looks good except for some information is redundant. The datatypes should be excluded and the identifier should be underlined. (ERD)

**Takeaway:** I should change the ERD and remove datatypes and underline identifiers, these steps should be implemented in the EER instead only.

<br>

**🌐 Technical Documentation** (unsolved)

**Reviewer:** Nick Schokker

**Feedback:** I like the structure of your technical documentation but i would say you can improve if you give a few visual example so its better to understand with the text

**Takeaway:**  I should add short and concise code snippet to the technical doc aswell to make it more readable.

<br>

## Performance Review Week 2
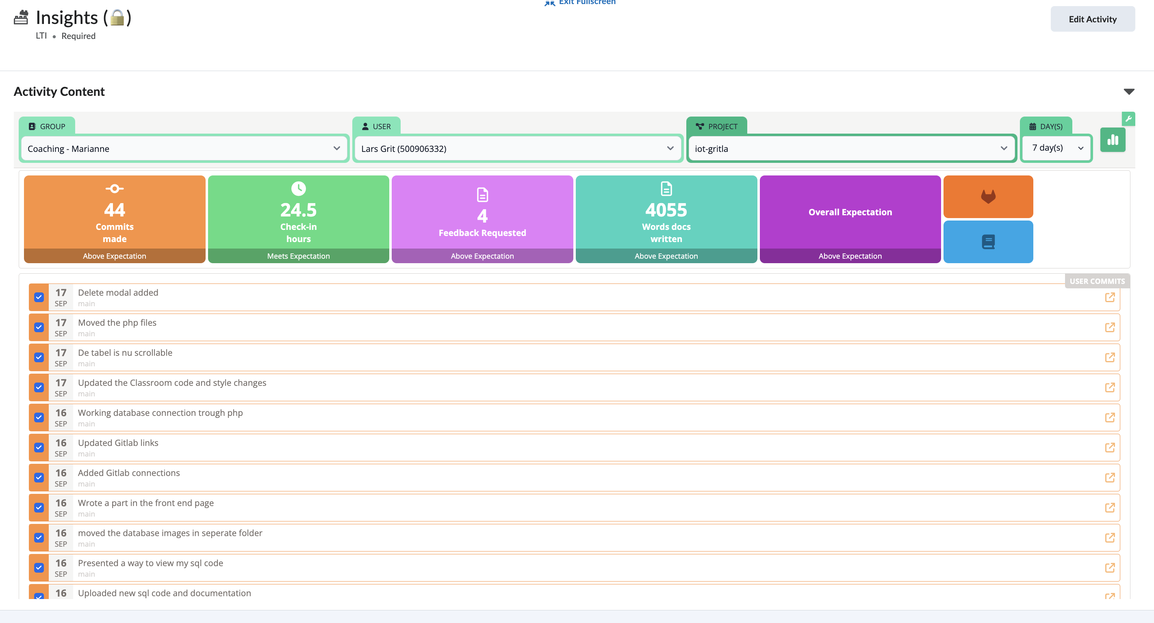
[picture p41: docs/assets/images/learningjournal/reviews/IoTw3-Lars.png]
performance review


<br>

---

## Week 3

Week 3 started with User Experience Design, by following a laser cutting workshop of Joey. Here I learnt how to use a lasercutting machine and what to look out for. Following this workshop I wanted to do more research in 2d and 3d cadding and followed a tutorial on 2d CADding which I could apply to laser cutting.

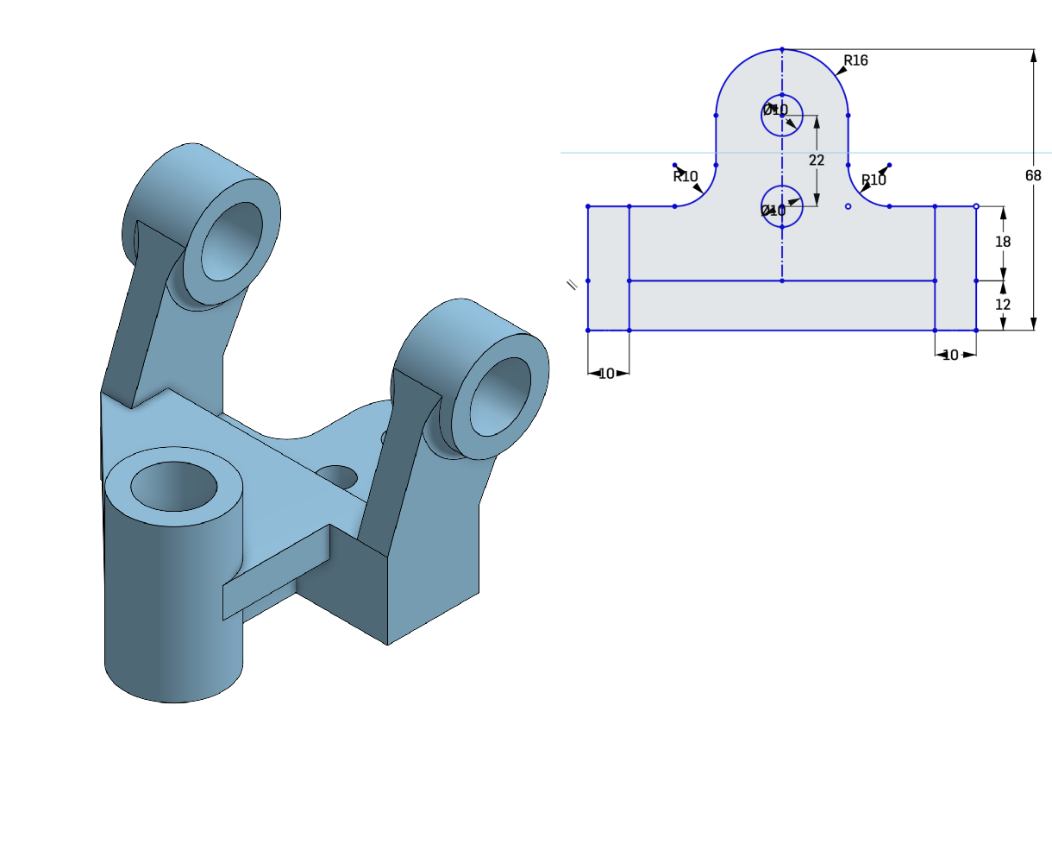
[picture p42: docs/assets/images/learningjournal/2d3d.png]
2D&3D cadding


I then worked on embedded and getting it connected to the web, last week I got the esp32 connected to the wifi but now I had to figure out how to get it to send actual data. In php I started setting up the rest API to collect data from the esp32. and on the esp32 I had to figure out how to use post requests to send the data to my website through the API. Next step would be to collect data from the site to the esp32 for displaying user name on the LCD for example.

For the embedded parts I had to figure out how to use capacitors and use it with the DCDC mini converter to get nice stable voltage flowing through the device and convert that batteries 9v to 5v for both powering the esp32 itself but also the DHT11 and LCD. I also added a DHT11 sensor that every so often updates the system by sending internal temperatures and humidity. Multiple LEDS for status showing power, wifi connection and card scanned and buttons for selecting modes.

Along with updating the proper documentation for it and debugging the embedded hardware and software took two days time aswell.

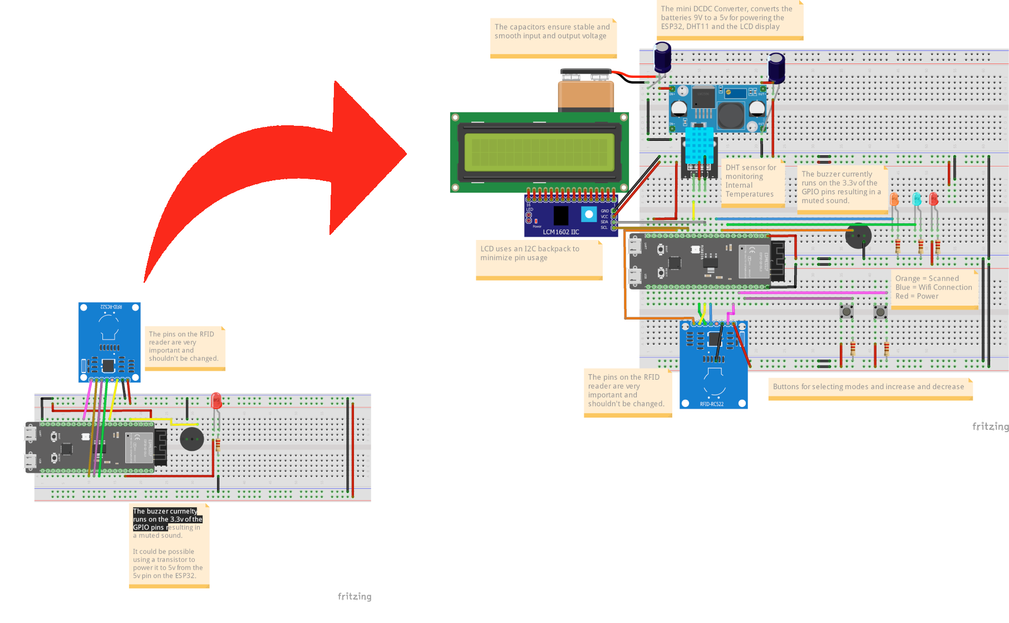
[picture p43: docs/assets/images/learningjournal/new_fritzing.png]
new fritzing diagrams


<br>

### Feedback
**👩‍🎨 Concept & Design** (solved)

**Reviewer:** Lucas Hilgevoord 

**Feedback:** I would brothen [broaden] your userbase a bit, so not only 3rd year students, but all the students of HvA. Looks good for the rest!

**Takeaway:** I should change my userbase and scope to make the project available for all hva studenten since they will all have the hva ID's required to make the project.

<br>

**👩‍🎨 Concept & Design** (unsolved)

**Reviewer:**  Simon Sweerz

**Feedback:** Ik denk dat het idee van SMART requirements is dat je meerdere requirements hebt, die allemaal SMART geformuleerd zijn. Voor de rest leg je goed uit voor wie beertracker is en waarvoor het is bedoelt.

**Takeaway:** Ik moet meerdere smart doelen maken.

<br>

## Performance Review Week 3
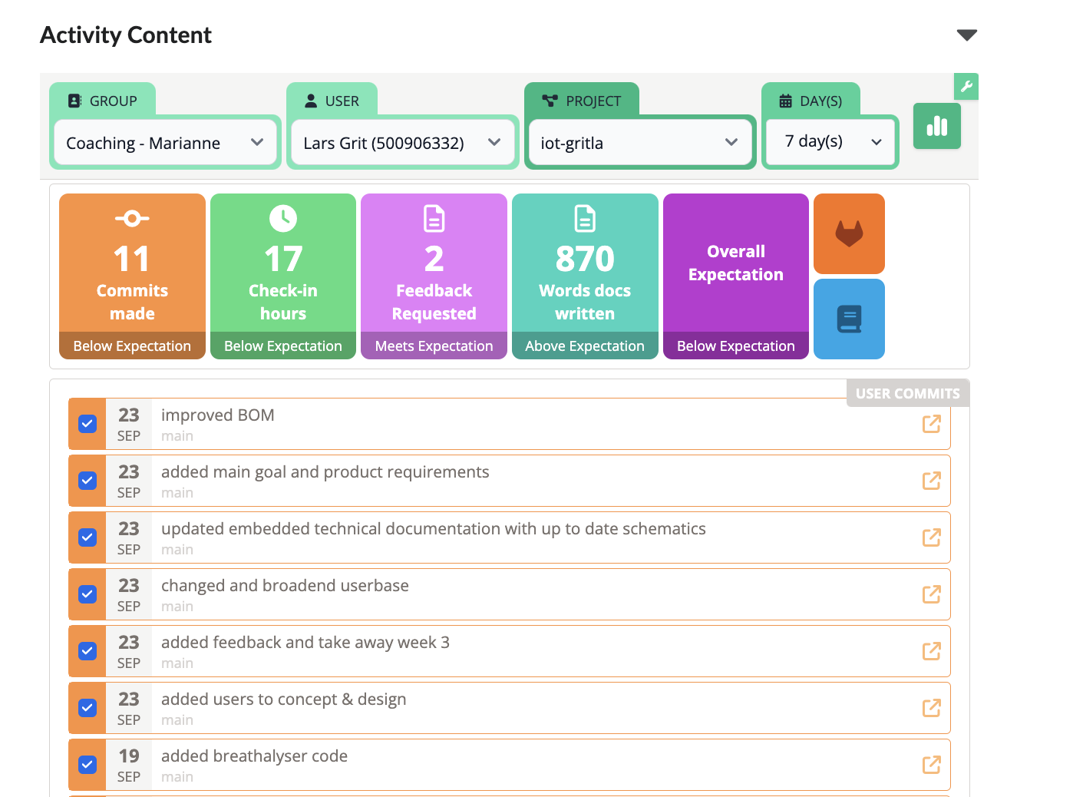
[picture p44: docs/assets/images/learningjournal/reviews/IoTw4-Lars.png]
performance review


Sadly this week I got below average, due to much time spent on learning CAD and working on and debugging hardware I did not have enough commits. Combined with being sick and not attending school on the friday.

<br>

---

## Week 4
The week started with writing a lot of documentation, I was lacking behind especially with Concept & Design (the feedback counted for week 3). The rest of week was primarily working on my api and embedded to get two communication working. This was a longer than anticipated task seeing how my esp32 also died during it and I didn't know for a whole day trying to debug. But I managed to create a two way communication where the esp32 sends the card UID and it receives the user's name associated with that UID, back from the api to display it on the LCD.

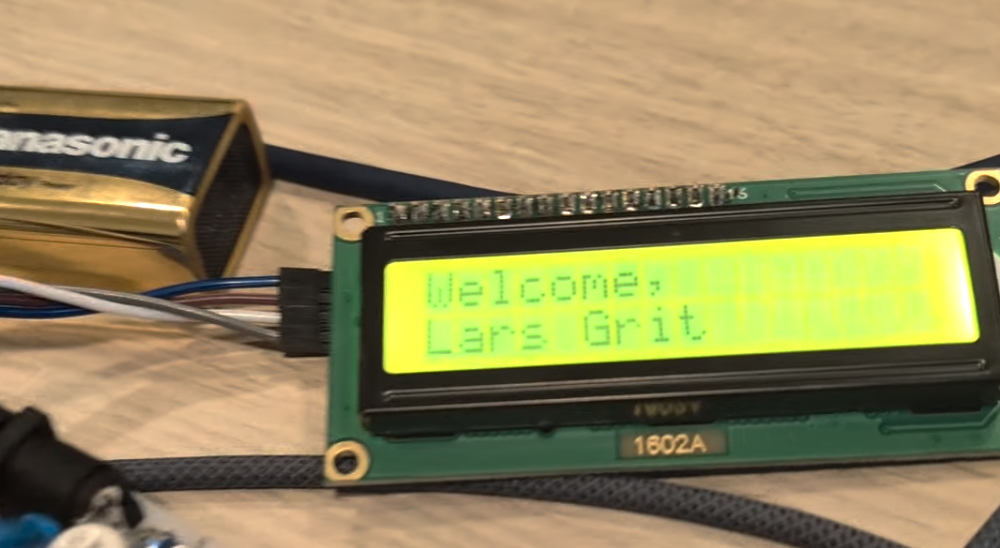
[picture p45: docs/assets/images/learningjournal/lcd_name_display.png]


<br>

### Feedback
**👩‍🎨 Concept & Design** (unsolved)

**Reviewer:** Koen Lammers

**Feedback:** Hi Lars, please take into account that pla has a low glass transition point. this means that when your device is on a table on a sunny day, it might get soft or melt. for the summer it would be better to use a material like PETG, which has a higher glass transition temperature.

**Takeaway:** For prototyping I can use PLA but for the end product it should be better to use PETG to ensure the encasing doesnt melt or get soft.

<br>

## Performance Review Week 4
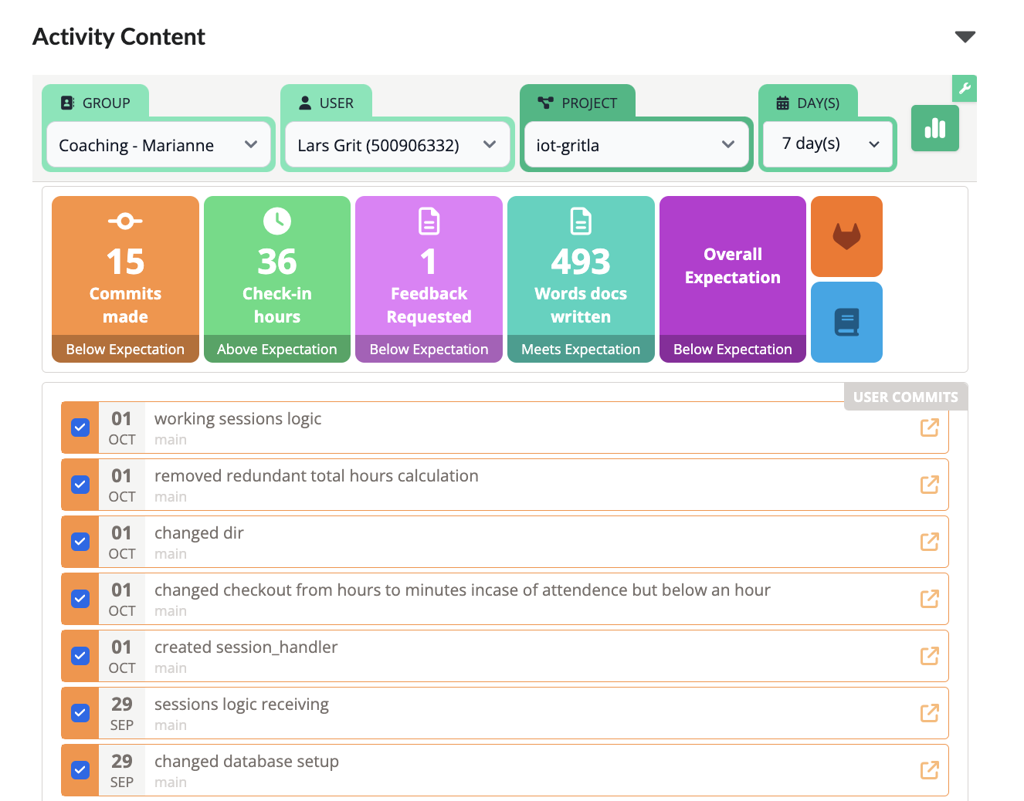
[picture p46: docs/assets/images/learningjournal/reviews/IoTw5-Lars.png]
performance review


Sadly again, another week of below expectations. I put in the hours but due to a lot of debugging hardware this weekend with non functional esp32's and sickness lowering my productivity I'm not there 100% and it shows on the performance review.

<br>

---

## Week 5

This week I did a lot of work implementing the api and back-end logic for the clock in clock out system, in the form of sessions. Sessions are day(s) bound where users can check in and check out using the rfid scanner (tested using Postman to make post requests). Their timestamps are recorded and a total is adjusted. On the embedded side there has been a lot of research and rebuilding. To begin my esp32-s3 has been replaced by a esp32-32 after showing faulty activity, the reason why I picked the esp32-32 was due to the fact of the 5v output which resulted in not needing to use the 9v battery and the dcdc converter resulting in a simpler hardware setup.

ESP3232 setup

With this implemented I was closing in on finishing my blueprint on the code and hardware side. However my RFID scanner is very inconsistent in it working, which lead to more research and replacing my rfid rc522 with a PN532 due to it's ability to work with i2c. The i2c protocol is already being used in the project for the LCD and works well, while the ISP connection of the old rfid scanner is very inconsistent.

Last thing to be implemented was a heartbeat wifi connection to see if the esp32 is connected with the wifi and able to see it on the websites. The esp32 send an occasional heartbeat to the database with a healthy connection status and a timestamp. and on the website they look at the time stamp and see if it is in the websites frequency of (30 seconds).s

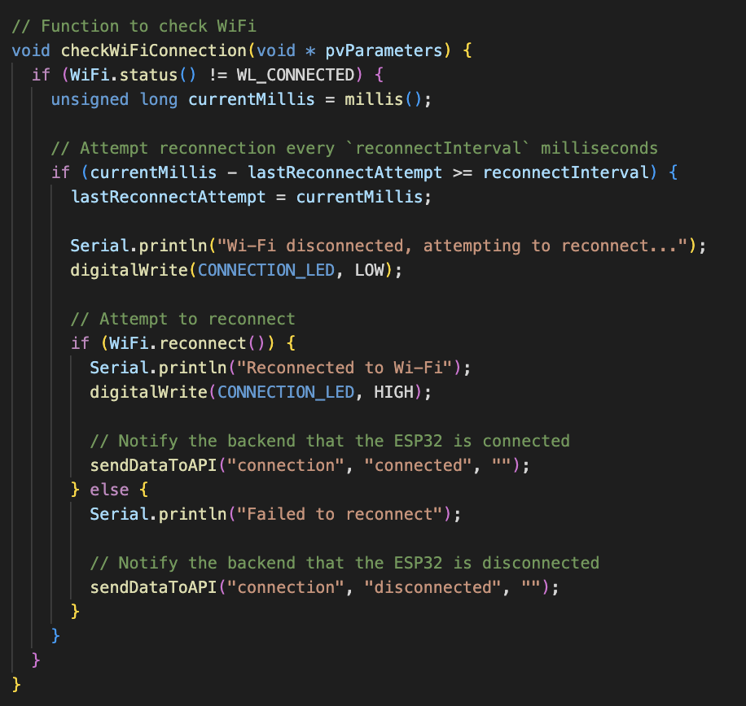
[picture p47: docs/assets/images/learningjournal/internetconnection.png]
internet connection setup


<br>

### Feedback

<br>

**🌐 API Reference** (solved)

**Reviewer:** Lucas Hilgevoord

**Feedback:** Looks good! Nicely formatted :D

**Takeaway:** N/A

<br>

## Performance Review Week 5
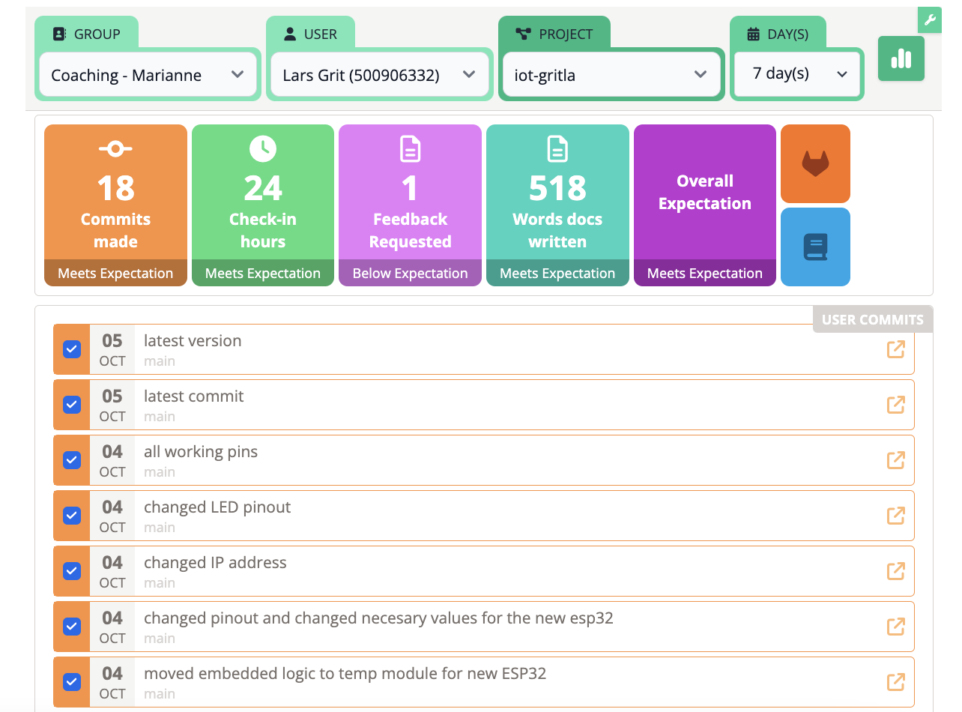
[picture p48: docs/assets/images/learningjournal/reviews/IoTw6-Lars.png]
performance review


<br>

---

## Week 6

This week I was sick and absent.

<br>

## Performance Review Week 6

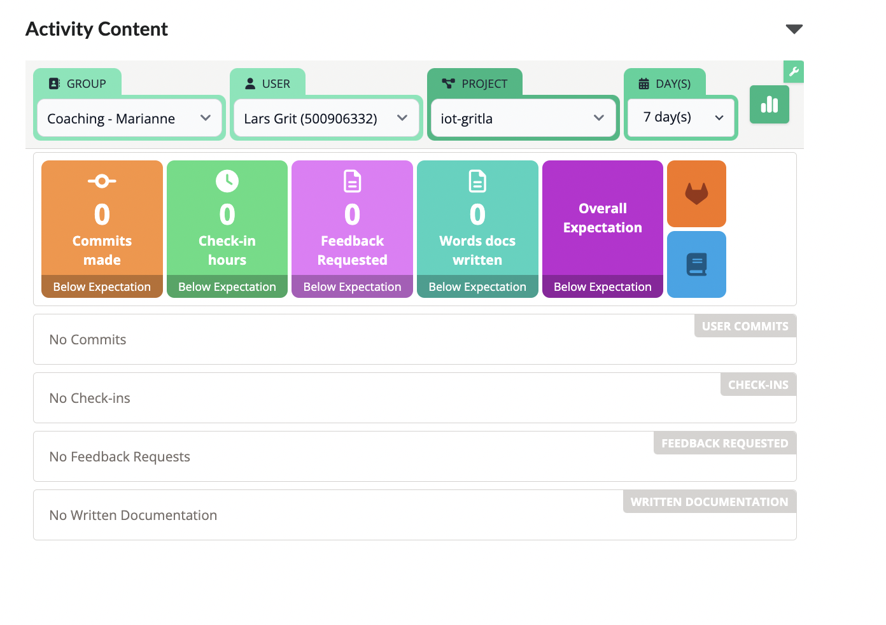
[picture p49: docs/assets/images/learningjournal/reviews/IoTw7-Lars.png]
performance review


<br>

---

## Week 7

After healing from my sickness I started developing with the PN532 RFID sensor and making it work with i2c. I had to learn how to handle multiple i2c devices by using their specific i2c addresses. A lot of time was spent working on and debugging the code of the PN532 on multiple platforms to get a solid and consistent scanning workflow. 

The rest of the week was spent fully on UED with using CAD to create a physical housing for the device. I went through 15~ versions of the current design before landing on something that I was happy with and that worked and that I could use forward. It was not only a process of creating a design but also learning CAD itself and learning new techniques to further my project design. This also required a lot of trial and error getting parts to fit well and be placed well to keep enough space for every part.

<br>

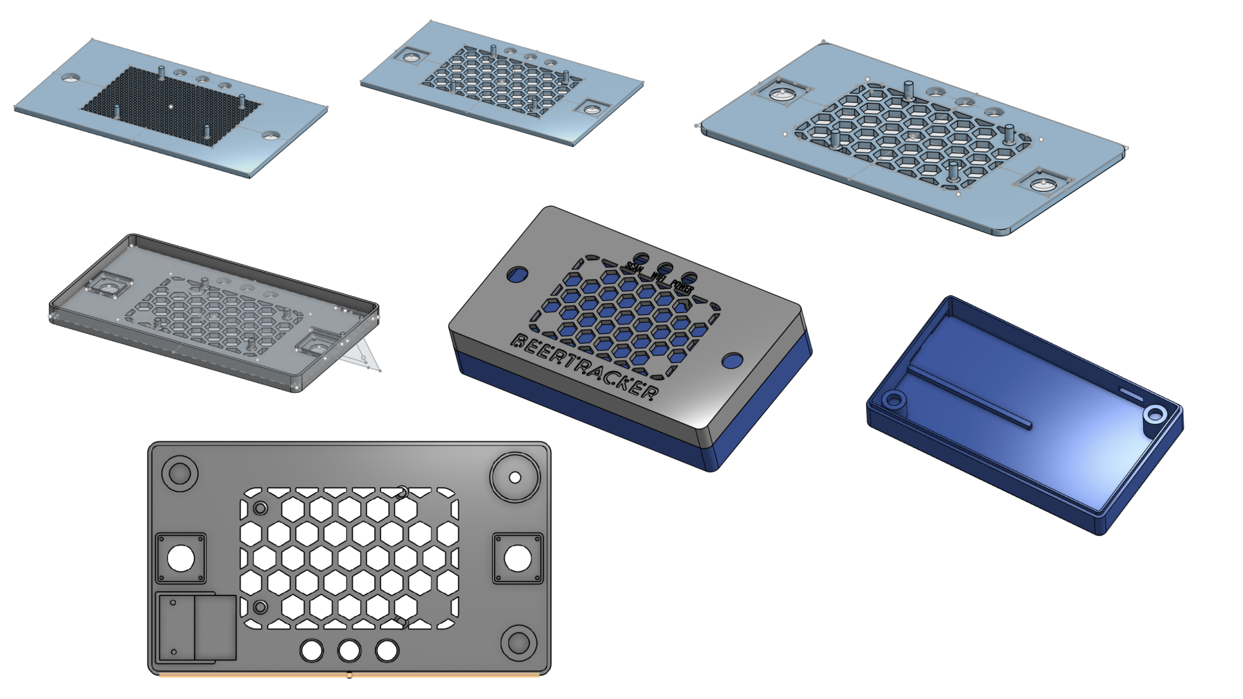
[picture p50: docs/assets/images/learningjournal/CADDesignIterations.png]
Multiple CAD Design iterations


*Multiple CAD design iterations*

<br>

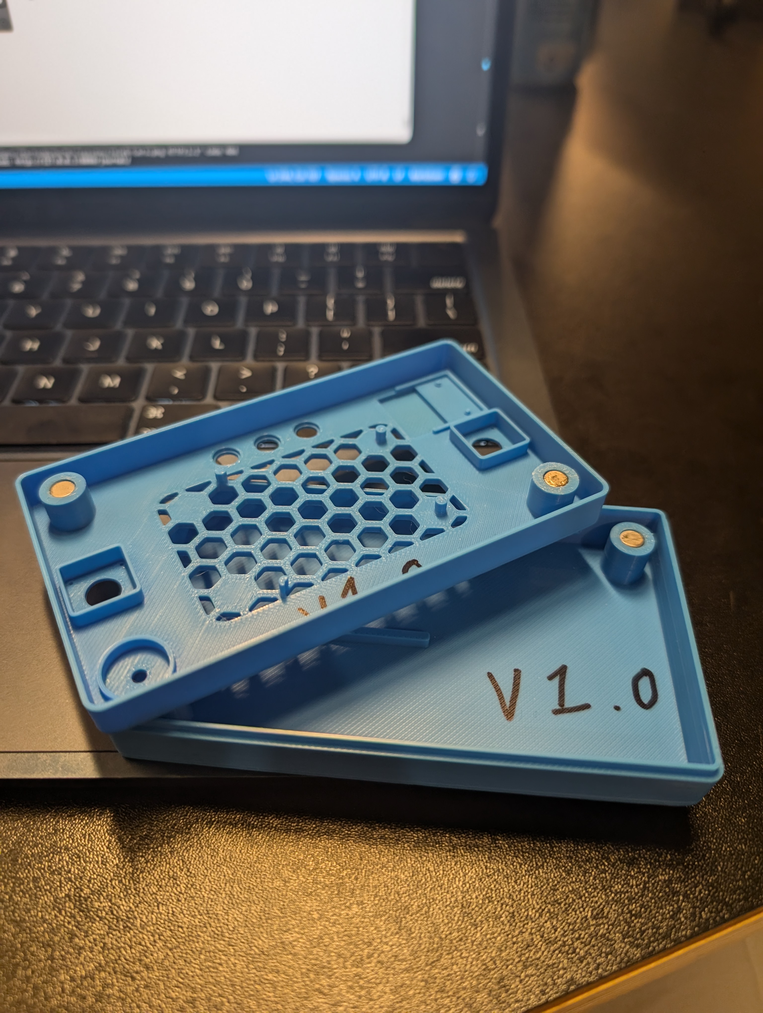
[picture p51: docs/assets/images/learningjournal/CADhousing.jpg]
My CAD housing


*Printed physical product*

<br>

### Feedback

<br>

**🌐 👩‍🎨 Concept & Design** (unsolved)

**Reviewer:** Nick Schokkers

**Feedback:** Looks good to me

**Takeaway:** Helpful...

<br>

## Performance Review Week 7

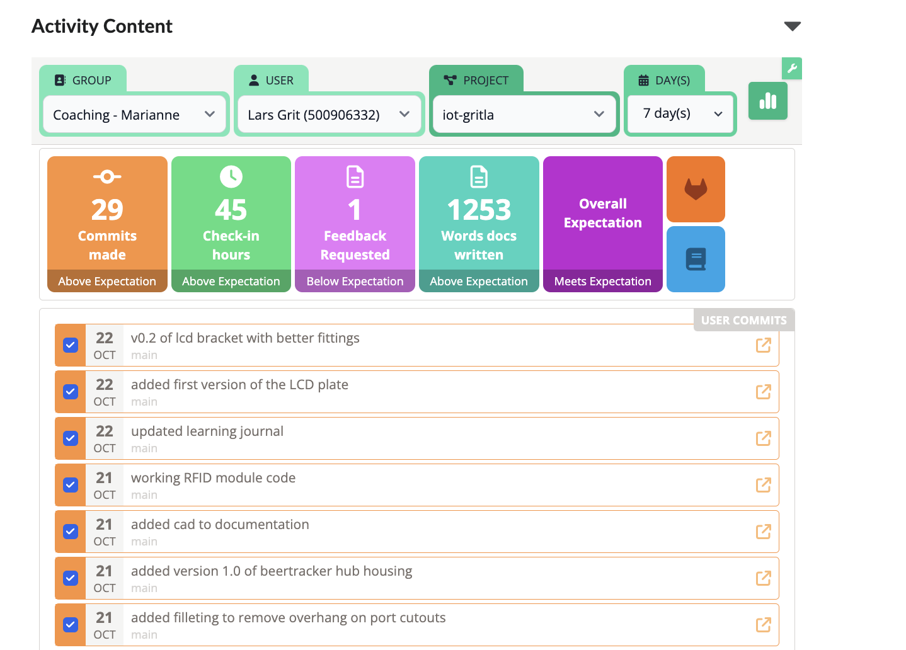
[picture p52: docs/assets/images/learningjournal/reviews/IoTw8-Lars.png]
performance review

glu
<br>

Made great progress today and the performance review looks good, sadly I didn't request enough feedback

---

## Week 8

Week 8 begun with looking into my research for my project, I have two main subjects I'm working on further development with PCB design and Accesibility in UX, specifically the less fortunate in sight. In addition to exploring PCB design and accessibility, I investigating how humans react to specific sounds, which can be useful for implementing a buzzer in my project to deliver positive or negative feedback through different tones. Furthermore, I'm considering how Braille could be incorporated to enhance accessibility, alongside potential voice activation features that would allow users to interact with the device hands-free and without needing sight. This combination could significantly improve usability for visually impaired individuals. To test my product on accesibility aswell I started making up user tests for people to test my design and find edge cases and issue's people could have with the workflow of my device.

I worked on implementing the buttons to work smoothly in my embedded code by giving a small enough delay for allowing people to hold down the button to cycle and using LCD visual and buzzer audible feedback on changing options. 

This week also included a massive website front-end overhaul using bootstrap, creating multiple tabs to divide the website and having a place for a dashboard to show fun and necessary information.

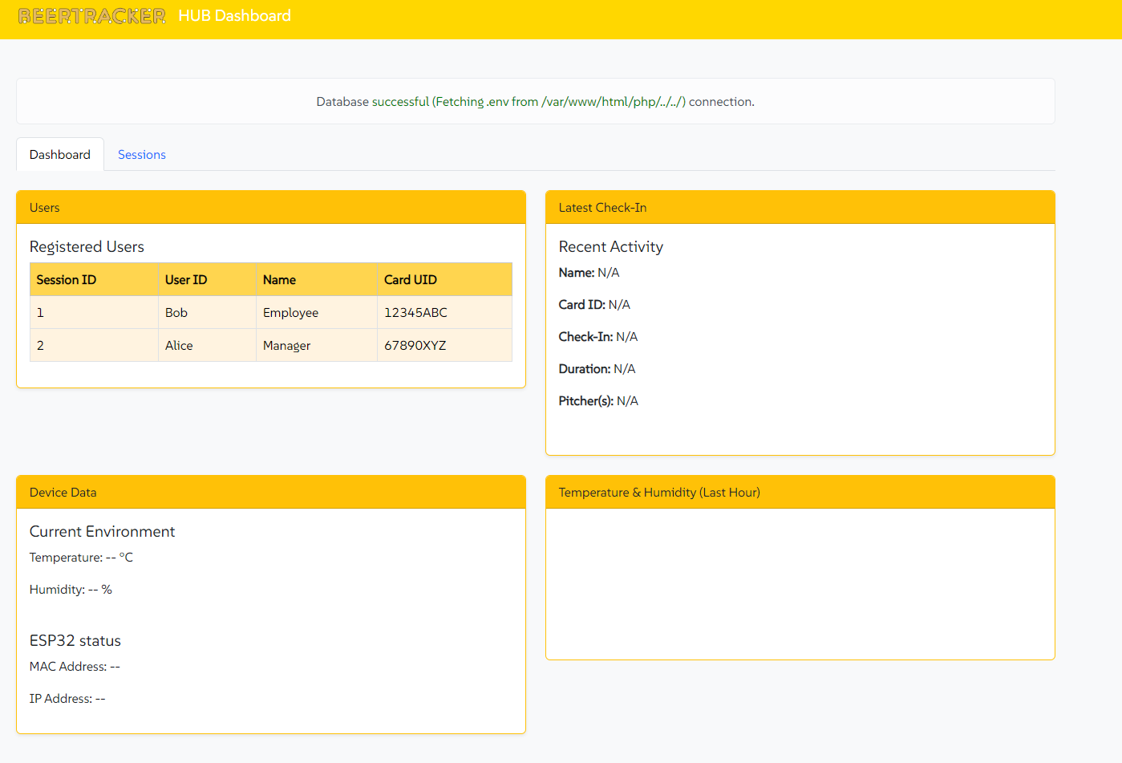
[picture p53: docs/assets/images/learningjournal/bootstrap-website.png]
bootstrap-website overhaul


This week also involved significant CAD work, focusing on creating a custom bracket for the LCD that securely latches onto the main device. It was a challenging task to design a bracket that worked seamlessly within the device’s size constraints, requiring careful adjustments to ensure both stability and functionality.

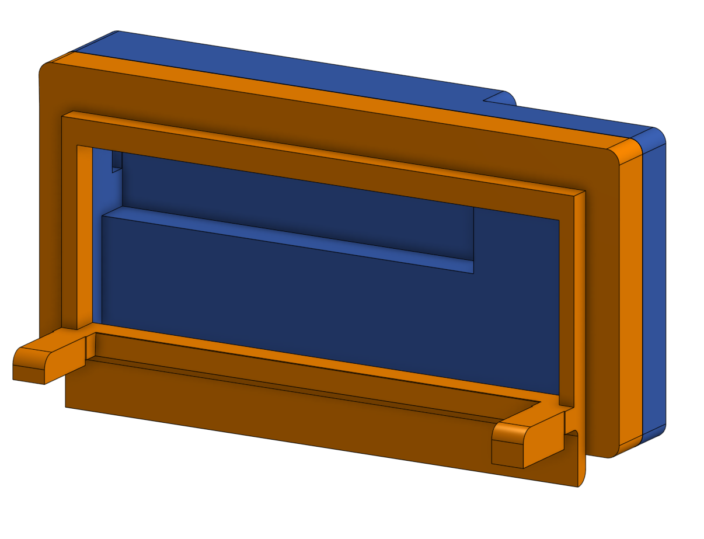
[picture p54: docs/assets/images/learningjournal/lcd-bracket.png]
LCD bracket


For the main device, I experimented with a fun drink-pattern design. I started by sketching and extruding patterns in alternating directions, then mirrored them for symmetry. Using Boolean tools, I refined the pattern by selectively intersecting and subtracting parts to create a cohesive, layered effect that mimics a bubbly drink texture.

Creating the drink pattern turned out to be quite a challenge, largely due to the main device's rounded corners. Since the fillets were made as sketch fillets, working around them required careful alignment and extra precision to get the pattern to flow seamlessly across the curved edges. Integrating each layer without disrupting the filleted corners added a lot of complexity, but with iterative adjustments, I managed to achieve a cohesive design that maintained the bubbly, drink-like aesthetic.

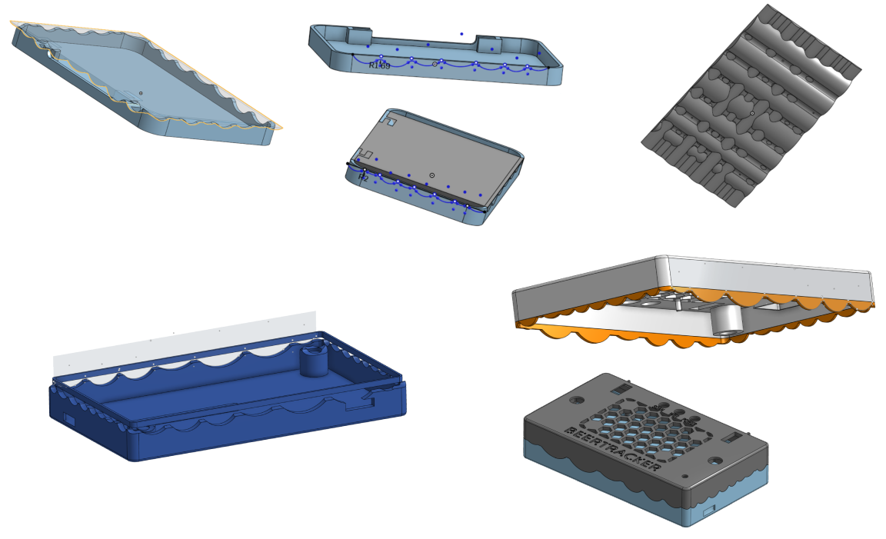
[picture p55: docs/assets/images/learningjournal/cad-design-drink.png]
The drink design of the lcd bracket


<br>

### Feedback

<br>

**🌐 👩‍🎨 Concept & Design** (unsolved)

**Reviewer:** Koen Lammers

**Feedback:** 

**Takeaway:** 

<br>

## Performance Review Week 8

performance review

<br>

## Week 9

Week 9 begun with

<br>

### Feedback

<br>

## Performance Review Week 9

performance review

<br>

## Week 10

Week 10 begun with

<br>

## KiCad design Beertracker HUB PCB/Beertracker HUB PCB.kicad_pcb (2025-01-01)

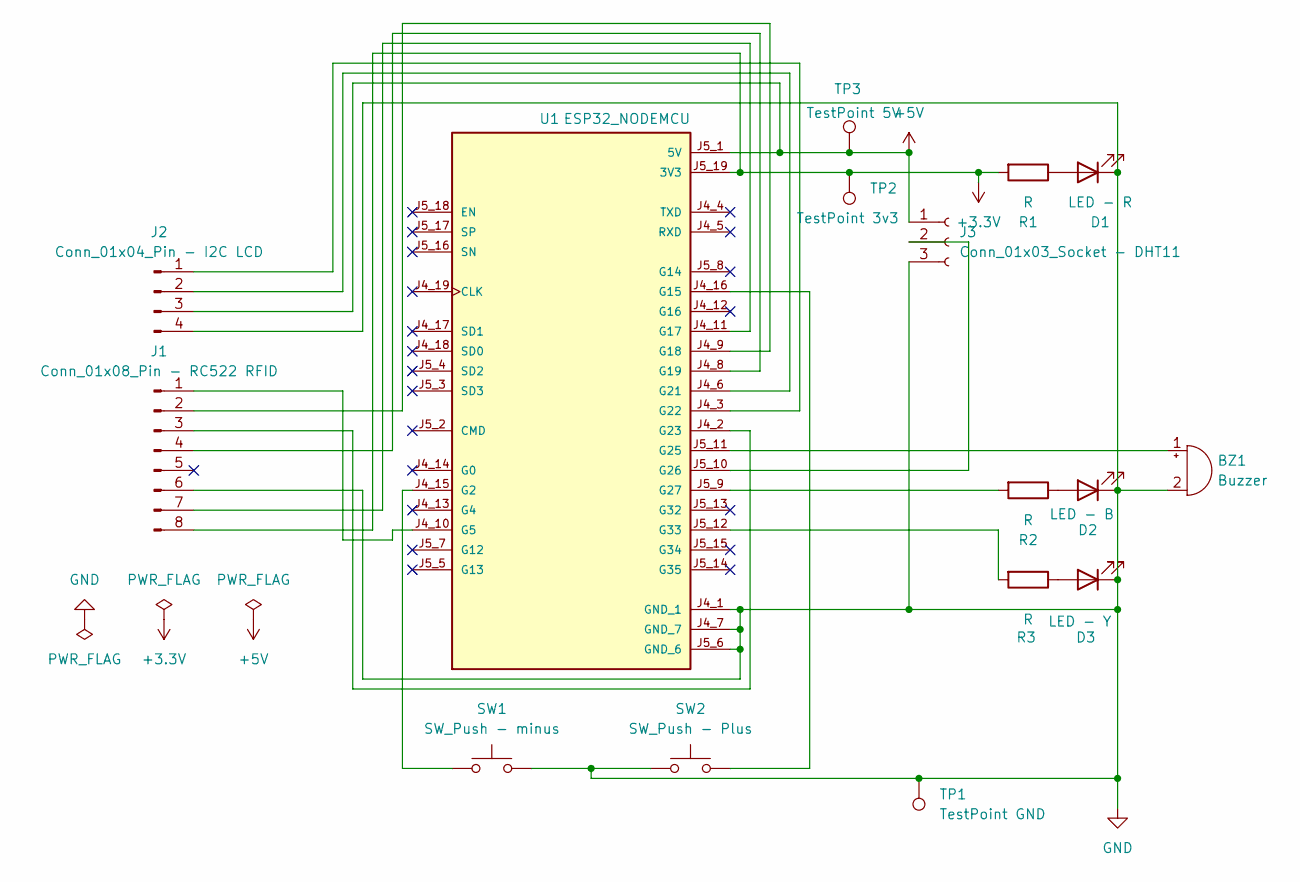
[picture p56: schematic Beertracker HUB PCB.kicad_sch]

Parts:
BZ1: Buzzer; Buzzer_12x9.5RM7.6
D1: LED - R; LED_D5.0mm
D2: LED - B; LED_D5.0mm
D3: LED - Y; LED_D5.0mm
J1: Conn_01x08_Pin - RC522 RFID; PinHeader_1x08_P2.54mm_Vertical
J2: Conn_01x04_Pin - I2C LCD; PinHeader_1x04_P2.54mm_Vertical
J3: Conn_01x03_Socket - DHT11; PinSocket_1x03_P2.54mm_Vertical
R1, R2, R3: R; R_Axial_DIN0207_L6.3mm_D2.5mm_P7.62mm_Horizontal
SW1: SW_Push - minus; SW_PUSH_6mm_H5mm
SW2: SW_Push - Plus; SW_PUSH_6mm_H5mm
TP1: TestPoint GND; TestPoint_Pad_1.5x1.5mm
TP2: TestPoint 3v3; TestPoint_Pad_1.5x1.5mm
TP3: TestPoint 5V; TestPoint_Pad_1.5x1.5mm
U1: ESP32_NODEMCU; MODULE_ESP32_NODEMCU

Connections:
+3.3V: J1.8, R1.2, TP2.1, U1.J5_19 (3V3)
+5V: J2.3, J3.1, TP3.1, U1.J5_1 (5V)
GND: BZ1.2 (-), D1.1 (K), D2.1 (K), D3.1 (K), J1.6, J2.4, J3.3, SW1.2, SW2.1, TP1.1, U1.J4_1 (GND_1), U1.J4_7 (GND_7), U1.J5_6 (GND_6)
unnamed: BZ1.1 (+), U1.J5_11 (G25)
unnamed: D1.2 (A), R1.1
unnamed: D2.2 (A), R2.1
unnamed: D3.2 (A), R3.1
unnamed: J1.1, U1.J4_10 (G5)
unnamed: J1.2, U1.J4_9 (G18)
unnamed: J1.3, U1.J4_2 (G23)
unnamed: J1.4, U1.J4_8 (G19)
unnamed: J1.7, U1.J4_11 (G17)
unnamed: J2.1, U1.J4_3 (G22)
unnamed: J2.2, U1.J4_6 (G21)
unnamed: J3.2, U1.J5_10 (G26)
unnamed: SW1.1, U1.J4_15 (G2)
unnamed: SW2.2, U1.J4_16 (G15)
unnamed: R2.2, U1.J5_9 (G27)
unnamed: R3.2, U1.J5_12 (G33)

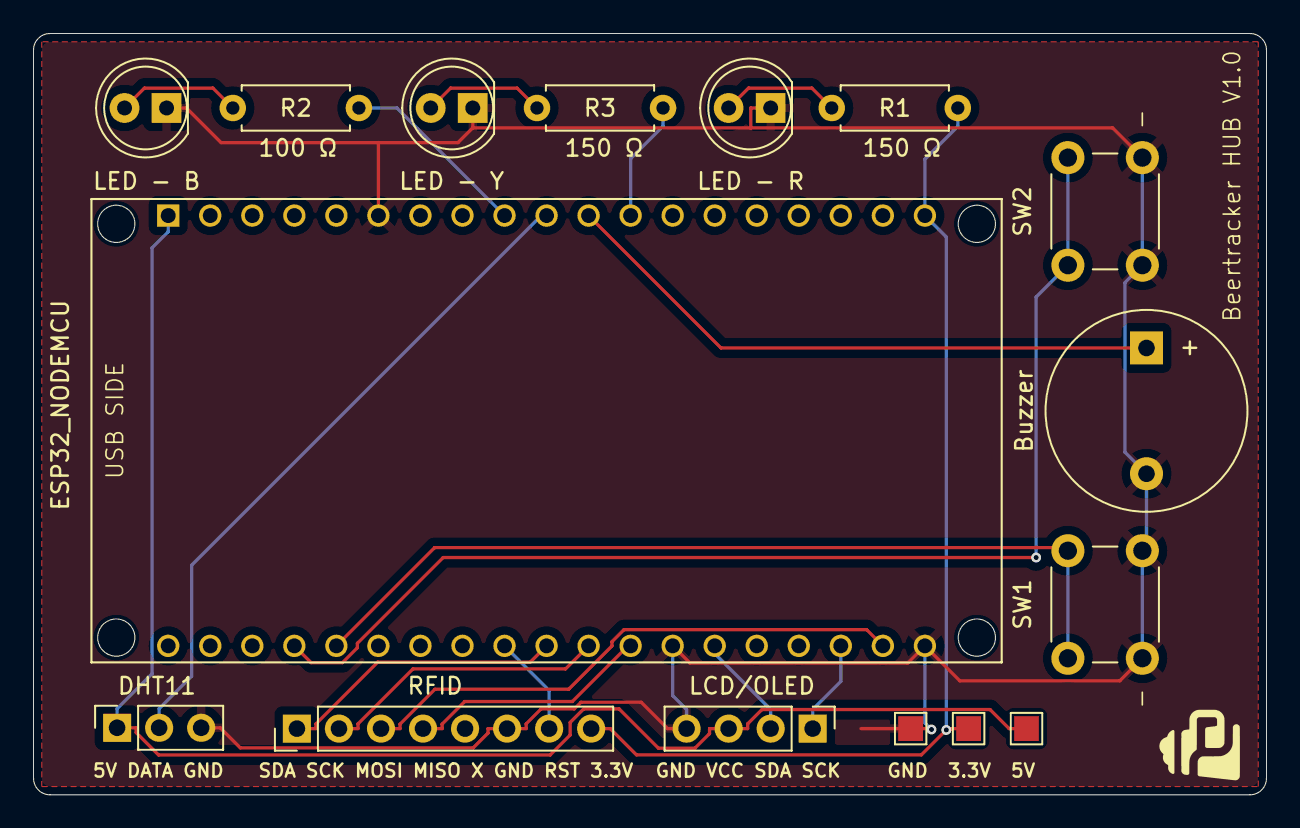
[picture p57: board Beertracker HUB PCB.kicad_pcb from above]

Board: 2 copper layers, 74.5 x 46.0 mm, 16 parts (0 on the bottom side), 19 nets.

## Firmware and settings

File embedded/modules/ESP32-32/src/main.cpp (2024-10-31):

#include <WiFiManager.h>
#include <Arduino.h>
#include <Wire.h>
#include <LiquidCrystal_I2C.h>
#include <SPI.h>
#include <MFRC522.h>
#include <DHT.h>
#include <Adafruit_Sensor.h>
#include <HTTPClient.h>
#include <ArduinoJson.h>


// Pin definitions
// SPI Pins
#define SS_PIN 5           // SDA/SS Pin for SPI
#define RST_PIN 17          // Reset Pin for SPI
#define SCK_PIN 18          // SCK Pin for SPI
#define MOSI_PIN 23         // MOSI Pin for SPI
#define MISO_PIN 19         // MISO Pin for SPI

// LED Pins
#define SCAN_LED 33         // LED Pin
#define CONNECTION_LED 27   // LED Pin

// Buzzer Pin
#define BUZZER_PIN 25       // Buzzer Pin

// Button Pins
#define DECREASE_BUTTON 15  // Button Pin - 
#define INCREASE_BUTTON 2  // Button Pin +

// Temperature Sensor Pin
#define TEMP_SENSOR 26       // Analog Pin
#define DHTTYPE DHT11       // DHT 11 type sensor

MFRC522 mfrc522(SS_PIN, RST_PIN);  // Create MFRC522 instance
DHT dht(TEMP_SENSOR, DHTTYPE);    // Create DHT instance

// Set the LCD address to 0x27 for a 16 chars and 2 line display
LiquidCrystal_I2C lcd(0x27, 16, 2);

// Flag to signal when card is detected
volatile bool cardDetected = false;

// Variable to store the card UID in hexadecimal format (e.g. "DEADBEEF") 
String cardUID = ""; 

// Variables for adjusting the wifi check function
unsigned long lastReconnectAttempt = 0;  // Global variable to track last reconnection attempt
const unsigned long reconnectInterval = 10000;  // Interval to try reconnecting (in milliseconds)

// Server IP
String serverIP = "http://192.168.50.170";

// Menu variables
volatile int currentMenuOption = 0;  // Track the current menu option (0 = Clock In, 1 = Clock Out, 2 = Add Pitcher)
const char* menuOptions[] = {"Clock In", "Clock Out", "Add Pitcher"};  // Menu options array
volatile bool menuUpdated = false;  // Flag to indicate menu option changed


// Forward declarations of task functions
void rfidTask(void * pvParameters);
void feedbackTask(void * pvParameters);
void temperatureTask(void * pvParameters);
void checkWiFiConnection(void * pvParameters);
void sendDataToAPI(String dataType, String data1, String data2);
void menuTask(void * pvParameters);
void heartbeatTask(void * pvParameters);
void addressTask(void * pvParameters);

void setup() {
  // Start serial communication
  Serial.begin(115200);
  Serial.println("Starting...");

  // Initialize SPI communication
  SPI.begin();
  Serial.println("SPI Initialized");

  // Initialize RFID reader
  mfrc522.PCD_Init();
  Serial.println("RFID Initialized");

  // Initialize DHT sensor
  dht.begin();
  Serial.println("DHT Initialized");

  // Initialize LED and buzzer pins as outputs
  pinMode(SCAN_LED, OUTPUT);       
  digitalWrite(SCAN_LED, LOW);    
  pinMode(CONNECTION_LED, OUTPUT);       
  digitalWrite(CONNECTION_LED, LOW);          
  pinMode(BUZZER_PIN, OUTPUT);

  // Intialize buttons as inputs
  pinMode(DECREASE_BUTTON, INPUT_PULLUP);
  pinMode(INCREASE_BUTTON, INPUT_PULLUP);

  // Create a Wi-Fi Manager object
  WiFiManager wifiManager;

  // This line resets saved Wi-Fi credentials
  // wifiManager.resetSettings();
  
  // Changes the theme to dark mode
  wifiManager.setClass("invert");

  // Automatically connect, or go to config portal if not connected
  if (!wifiManager.autoConnect("BeertrackerHUB™️ Wifi Portal", "3opMujJtembh6")) {
    Serial.println("Failed to connect and hit timeout");
    ESP.restart();
  }

  // If you get here you have connected to the WiFi
  Serial.println("Connected to Wi-Fi");
  digitalWrite(CONNECTION_LED, HIGH);

  // Initialize the LCD
  lcd.init();
  lcd.backlight();
  lcd.setBacklight(HIGH);
  lcd.setCursor(0, 0);

  // Multithreading setup for RFID and feedback tasks
  xTaskCreate(rfidTask, "RFID Task", 10000, NULL, 1, NULL);   // Task for RFID scanning
  xTaskCreate(feedbackTask, "Feedback Task", 10000, NULL, 2, NULL); // Task for feedback (LED/Buzzer)
  xTaskCreate(temperatureTask, "Temperature Task", 10000, NULL, 3, NULL); // Task for temperature readings
  xTaskCreate(menuTask, "Menu Task", 10000, NULL, 2, NULL);  // Task for the menu system
  xTaskCreate(heartbeatTask, "Heartbeat Task", 10000, NULL, 4, NULL); // Task for heartbeat
  xTaskCreate(addressTask, "Address Task", 10000, NULL, 5, NULL); // Task for address
}

void loop() {
}

// Task to continuously scan for RFID cards
void rfidTask(void * pvParameters) {
  Serial.println("RFID Task Started");
  while (true) {
    // Check if a new card is present
    if (mfrc522.PICC_IsNewCardPresent() && mfrc522.PICC_ReadCardSerial()) {
      // Store the card UID
      cardUID = "";
      for (byte i = 0; i < mfrc522.uid.size; i++) {
        cardUID += String(mfrc522.uid.uidByte[i], HEX);
      }
      cardUID.toUpperCase();
      Serial.println("Card detected: " + cardUID);

      cardDetected = true;  // Set flag to indicate card is detected for feedback task

      // Send the card UID to the API and get the username
      sendDataToAPI("card", cardUID, String(currentMenuOption));

      // Halt the PICC to prevent repeated scans
      mfrc522.PICC_HaltA();
    }

    // Delay between checks
    vTaskDelay(100 / portTICK_PERIOD_MS);  // 100 ms delay for task switching
  }
}


// Task to handle feedback (LED and Buzzer) when a card is detected
void feedbackTask(void * pvParameters) {
  while (true) {
    if (cardDetected) {
      // Turn on the LED
      digitalWrite(SCAN_LED, HIGH);

      // Play a sound for feedback
      tone(BUZZER_PIN, 523);  // Play tone C4
      vTaskDelay(100);             
      noTone(BUZZER_PIN);
      tone(BUZZER_PIN, 784);  // Play tone G4
      vTaskDelay(100);             
      noTone(BUZZER_PIN);

      // Turn off the LED
      digitalWrite(SCAN_LED, LOW);

      // Keep the feedback visible for a short period
      vTaskDelay(500);             

      cardDetected = false;  // Reset flag after feedback is given
    }

    // Delay between checks
    vTaskDelay(10 / portTICK_PERIOD_MS);  // 10 ms delay for task switching
  }
}


// Task to continuously read the temperature
void temperatureTask(void * pvParameters) {
  while (true) {
    // Read temperature from DHT sensor
    float temperature = dht.readTemperature();
    float humidity = dht.readHumidity();
    
    // Check if the reading is valid
    if (isnan(temperature)) {
      Serial.println("Failed to read from DHT sensor!");
    } else {
      Serial.print("Temperature: ");
      Serial.print(temperature);
      Serial.println("°C");
      Serial.print("Humidity: ");
      Serial.print(humidity);
      Serial.println("%");

      // Send temperature and humidity to API
      sendDataToAPI("temperature", String(temperature), String(humidity));
    }
    
    // Delay for 30 seconds (30000 ms)
    vTaskDelay(60000 / portTICK_PERIOD_MS);
  }
}


// Function to check WiFi
void checkWiFiConnection(void * pvParameters) {
  if (WiFi.status() != WL_CONNECTED) {
    unsigned long currentMillis = millis();
    
    // Attempt reconnection every `reconnectInterval` milliseconds
    if (currentMillis - lastReconnectAttempt >= reconnectInterval) {
      lastReconnectAttempt = currentMillis;
      
      Serial.println("Wi-Fi disconnected, attempting to reconnect...");
      digitalWrite(CONNECTION_LED, LOW);
      
      // Attempt to reconnect
      if (WiFi.reconnect()) {
        Serial.println("Reconnected to Wi-Fi");
        digitalWrite(CONNECTION_LED, HIGH);

        // Notify the backend that the ESP32 is connected
        sendDataToAPI("connection", "connected", "");
      } else {
        Serial.println("Failed to reconnect");

        // Notify the backend that the ESP32 is disconnected
        sendDataToAPI("connection", "disconnected", "");
      }
    }
  }
}

void menuTask(void *pvParameters) {
  Serial.println("Menu Task Started");

  // Variable to track the last selection time
  unsigned long lastSelectionTime = 0;
  const unsigned long selectionDisplayDuration = 3000; // 3 seconds in milliseconds
  bool selectionActive = false; // Flag to check if an option is selected

  while (true) {
    // Check if LEFT button is pressed
    if (digitalRead(DECREASE_BUTTON) == LOW) {
      Serial.println("Minus (LEFT) button pressed");
      currentMenuOption--;
      if (currentMenuOption < 0) {
        currentMenuOption = 2;  // Wrap around to the last option (Add Pitcher)
      }
      menuUpdated = true;
      vTaskDelay(150 / portTICK_PERIOD_MS); // Moderate debounce delay
    }

    // Check if RIGHT button is pressed
    if (digitalRead(INCREASE_BUTTON) == LOW) {
      Serial.println("Plus (RIGHT) button pressed");
      currentMenuOption++;
      if (currentMenuOption > 2) {
        currentMenuOption = 0;  // Wrap around to the first option (Clock In)
      }
      menuUpdated = true;
      vTaskDelay(150 / portTICK_PERIOD_MS); // Moderate debounce delay
    }

    // If menu updated, show the new option on the LCD
    if (menuUpdated) {
      tone(BUZZER_PIN, 1000);  // Play a tone to indicate menu change
      lcd.clear();
      lcd.setCursor(0, 0);
      lcd.print("Option:");
      lcd.setCursor(0, 1);
      lcd.print(menuOptions[currentMenuOption]);
      vTaskDelay(100);             
      noTone(BUZZER_PIN);
      
      // Mark the selection as active and record the time
      selectionActive = true;
      lastSelectionTime = millis();
      menuUpdated = false;
    }

    // Check if selection is active and duration has passed
    if (selectionActive && (millis() - lastSelectionTime >= selectionDisplayDuration)) {
      lcd.clear(); // Clear the LCD after the duration
      selectionActive = false; // Reset selection state
    }

    // Small delay before the next loop iteration
    vTaskDelay(50 / portTICK_PERIOD_MS); // Keep it responsive
  }
}

// Function to send data to API
void sendDataToAPI(String dataType, String data1, String data2) {
  if (WiFi.status() == WL_CONNECTED) {  // Check WiFi connection status
    HTTPClient http;
    http.setTimeout(5000);  // Set a 5-second timeout for the request

    http.begin(serverIP + "/php/api.php"); // Specify the URL of the API endpoint
    http.addHeader("Content-Type", "application/x-www-form-urlencoded");  // Set the POST content type

    String postData = "";

    if (dataType == "temperature") {
      Serial.println("Sending temperature and humidity data to API");
      // Send temperature and humidity data
      postData = "type=temperature&temperature=" + data1 + "&humidity=" + data2;
    } else if (dataType == "card") {
      Serial.println("Sending card UID data to API");
      // Send card UID data
      postData = "type=card&uid=" + data1 + "&option=" + data2;
    } else if (dataType == "heartbeat") {
      Serial.println("Sending ESP32 heartbeat to API");
      postData = "type=heartbeat&status=" + data1;
    } else if (dataType == "address") {
      Serial.println("Sending ESP32 address to API");
      postData = "type=address&ip=" + data1 + "&mac=" + data2;
    }


    // Send the POST request
    int httpResponseCode = http.POST(postData);

    if (httpResponseCode > 0) {
      Serial.print("HTTP Response code: ");
      Serial.println(httpResponseCode);

      // If card data is being sent, handle the response
      if (dataType == "card") {
        String response = http.getString();
        Serial.println("Response: " + response);

        // Parse the JSON response to get the username
        DynamicJsonDocument doc(1024);
        DeserializationError error = deserializeJson(doc, response);
        if (!error) {
          const char* status = doc["status"];
          if (strcmp(status, "success") == 0) {
            const char* userName = doc["name"];
            Serial.print("Username: ");
            Serial.println(userName);

            // Display the username on the LCD
            lcd.clear();
            if (currentMenuOption == 0) { // Clock In
              lcd.print("Welcome,");
            } else if (currentMenuOption == 1) { // Clock Out
              lcd.print("Bye,");
            } else if (currentMenuOption == 2) { // Add Pitcher
              lcd.print("+1 Pitcher,");
            }
            lcd.setCursor(0, 1);
            lcd.print(userName);  // Display the username on the second line

            // Keep the text visible for a short period
            delay(2000);  // Wait 2 seconds
            lcd.clear();
          } else {
            // Handle various error statuses
            const char* message = doc["message"];
            Serial.println("Error: " + String(message));

            // Display the appropriate error message on the LCD
            lcd.clear();
            lcd.setCursor(0, 0);
            lcd.print("Error:");
            lcd.setCursor(0, 1);
            lcd.print(message);  // Display the error message

            // Keep the text visible for a short period
            delay(2000);  // Wait 2 seconds
            lcd.clear();
          }
        } else {
          Serial.println("Failed to parse response");
          // Handle parsing error
          lcd.clear();
          lcd.setCursor(0, 0);
          lcd.print("Parse Error");
          delay(2000);  // Wait 2 seconds
          lcd.clear();
        }
      }
    } else {
      Serial.print("Error on sending POST: ");
      Serial.println(httpResponseCode);
      // Display error on the LCD
      lcd.clear();
      lcd.setCursor(0, 0);
      lcd.print("HTTP Error:");
      lcd.setCursor(0, 1);
      lcd.print(httpResponseCode);
      delay(2000);  // Wait 2 seconds
      lcd.clear();
    }

    http.end();  // End the HTTP connection to free up resources
  } else {
    Serial.println("Error: WiFi not connected");
    // Display WiFi error on the LCD
    lcd.clear();
    lcd.setCursor(0, 0);
    lcd.print("WiFi Error");
    delay(2000);  // Wait 2 seconds
    lcd.clear();
  }
}

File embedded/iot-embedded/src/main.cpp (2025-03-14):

/*
 * MIT License
 * 
 * Copyright (c) [2024] Lars Grit
 * 
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
 * THE SOFTWARE IS PROVIDED "AS IS", WITHOUT WARRANTY OF ANY KIND, EXPRESS OR
 * IMPLIED, INCLUDING BUT NOT LIMITED TO THE WARRANTIES OF MERCHANTABILITY,
 * FITNESS FOR A PARTICULAR PURPOSE AND NONINFRINGEMENT. IN NO EVENT SHALL THE
 * AUTHORS OR COPYRIGHT HOLDERS BE LIABLE FOR ANY CLAIM, DAMAGES OR OTHER
 * LIABILITY, WHETHER IN AN ACTION OF CONTRACT, TORT OR OTHERWISE, ARISING FROM,
 * OUT OF OR IN CONNECTION WITH THE SOFTWARE OR THE USE OR OTHER DEALINGS IN THE
 * SOFTWARE.
 */

#include <WiFiManager.h>
#include <Arduino.h>
#include <Wire.h>
#include <SPI.h>
#include <MFRC522.h>
#include <DHT.h>
#include <Adafruit_Sensor.h>
#include <HTTPClient.h>
#include <ArduinoJson.h>
#include <ESPAsyncWebServer.h>
#include <base64.h>
#include "config.h"
#include <U8g2lib.h>

// Pin definitions
#define SS_PIN 5    // SDA/SS Pin for SPI
#define RST_PIN 17  // Reset Pin for SPI
#define SCAN_LED 33 // LED Pin
#define BUZZER_PIN 25 // Buzzer Pin
#define TEMP_SENSOR 26 // Analog Pin
#define DHTTYPE DHT11  // DHT 11 type sensor

MFRC522 mfrc522(SS_PIN, RST_PIN); // Create MFRC522 instance
DHT dht(TEMP_SENSOR, DHTTYPE);    // Create DHT instance

U8G2_SSD1306_128X32_UNIVISION_F_HW_I2C u8g2(U8G2_R0, /* reset=*/ U8X8_PIN_NONE, /* clock=*/ 22, /* data=*/ 21);
AsyncWebServer server(80);

volatile bool cardDetected = false;
String cardUID = "";
String serverIP = SERVER_URL;

void rfidTask(void *pvParameters);
void feedbackTask(void *pvParameters);
void temperatureTask(void *pvParameters);
void heartbeatTask(void *pvParameters);
void addressTask(void *pvParameters);
void sendDataToAPI(String dataType, String data1, String data2);

void setup() {
    Serial.begin(115200);
    Serial.println("Starting...");

    SPI.begin();
    mfrc522.PCD_Init();
    dht.begin();

    pinMode(SCAN_LED, OUTPUT);
    digitalWrite(SCAN_LED, LOW);
    pinMode(BUZZER_PIN, OUTPUT);

    // Initialize OLED
    u8g2.begin();
    u8g2.clearBuffer();
    u8g2.setFont(u8g2_font_6x10_tf);
    u8g2.drawStr(0, 10, "Beertracker WiFi");
    u8g2.drawStr(0, 30, "Connect to:");
    u8g2.drawStr(0, 40, "SSID: Beertracker WiFi");
    u8g2.drawStr(0, 50, "Pass: password123");
    u8g2.sendBuffer();

    WiFiManager wifiManager;
    if (!wifiManager.autoConnect("Beertracker WiFi", "password123")) {
        Serial.println("Failed to connect and hit timeout");
        u8g2.clearBuffer();
        u8g2.drawStr(0, 10, "WiFi Failed");
        u8g2.drawStr(0, 30, "Restarting...");
        u8g2.sendBuffer();
        delay(2000);
        ESP.restart();
    }

    Serial.println("Connected to Wi-Fi");

    // Update OLED to show WiFi connected
    u8g2.clearBuffer();
    u8g2.drawStr(0, 10, "WiFi Connected!");
    u8g2.sendBuffer();
    delay(1000);

    // Play startup sound
    tone(BUZZER_PIN, 1000);
    delay(100);
    noTone(BUZZER_PIN);

    // Show Initialization message
    u8g2.clearBuffer();
    u8g2.drawStr(0, 10, "Beertracker HUB");
    u8g2.drawStr(0, 30, "Initializing...");
    u8g2.sendBuffer();
    delay(100);
    u8g2.clearBuffer();

    // Start tasks
    xTaskCreate(rfidTask, "RFID Task", 10000, NULL, 1, NULL);
    xTaskCreate(feedbackTask, "Feedback Task", 10000, NULL, 2, NULL);
    xTaskCreate(temperatureTask, "Temperature Task", 10000, NULL, 3, NULL);
    xTaskCreate(heartbeatTask, "Heartbeat Task", 10000, NULL, 4, NULL);
    xTaskCreate(addressTask, "Address Task", 10000, NULL, 5, NULL);

    // Show scan message
    u8g2.clearBuffer();
    u8g2.drawStr(0, 10, "Beertracker");
    u8g2.drawStr(0, 30, "Scan card below");
    u8g2.sendBuffer();
}


void loop() {}

void rfidTask(void *pvParameters) {
    Serial.println("RFID Task Started");
    while (true) {
        if (mfrc522.PICC_IsNewCardPresent() && mfrc522.PICC_ReadCardSerial()) {
            // play a short beep
            tone(BUZZER_PIN, 1000, 100);
            vTaskDelay(100 / portTICK_PERIOD_MS);
            noTone(BUZZER_PIN);

            cardUID = "";
            for (byte i = 0; i < mfrc522.uid.size; i++) {
                cardUID += String(mfrc522.uid.uidByte[i], HEX);
            }
            cardUID.toUpperCase();
            Serial.println("Card detected: " + cardUID);

            // Step 1: Check if the user is clocked in
            HTTPClient http;
            http.begin(serverIP + "/api/card");
            http.addHeader("Content-Type", "application/x-www-form-urlencoded");

            // String credentials = base64::encode(String(API_USERNAME) + ":" + String(API_PASSWORD));
            // http.addHeader("Authorization", "Basic " + credentials);

            String postData = "uid=" + cardUID + "&option=0"; // Check clock-in status
            int httpResponseCode = http.POST(postData);

            if (httpResponseCode > 0) {
                String response = http.getString();
                Serial.println("Response: " + response);

                DynamicJsonDocument doc(2048); // Increased buffer size
                DeserializationError error = deserializeJson(doc, response);
                if (!error) {
                    const char *status = doc["status"];
                    const char *message = doc["message"];

                    Serial.print("Parsed Status: ");
                    Serial.println(status);
                    Serial.print("Parsed Message: ");
                    Serial.println(message);

                    if (strcmp(status, "success") == 0) {
                        const char *action = doc["action"];
                        const char *userName = doc["name"];
                        if (strcmp(action, "checked_in") == 0) {
                            // User is now clocked in
                            Serial.println("User clocked in: " + cardUID);
                            u8g2.clearBuffer();
                            u8g2.setFont(u8g2_font_6x10_tf);
                            u8g2.drawStr(0, 10, "Welcome,");
                            u8g2.drawStr(0, 30, userName);
                            u8g2.sendBuffer();

                            // Play "boom boom" sound
                            tone(BUZZER_PIN, 500, 200); // First tone: 500 Hz, 200 ms
                            vTaskDelay(300 / portTICK_PERIOD_MS);
                            tone(BUZZER_PIN, 700, 200); // Second tone: 700 Hz, 200 ms
                            vTaskDelay(300 / portTICK_PERIOD_MS);
                            noTone(BUZZER_PIN);
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

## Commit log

2024-09-05 the rfid scanner now only reads the card once and fires off a LED
2024-09-05 added delay for LED and card registation to avoid accidental registrations
    [main.cpp]
2024-09-05 added a buzzer to the rfid card scanner, and included necessary fritzing schematics
    [main.cpp]
2024-09-06 changed wiring diagrams for RFID scanner from WeMOS to ESP32-S3
2024-09-06 Changed RFID code to work on the esp32 instead of the WeMOS
2024-09-06 added the fritzing file to the assets folder
    [RFID RC522.fzz]
2024-09-06 Added the Technical Documentation for Embedded. Added items to BOM which are currently planned to be used and added WIP diagrams
2024-09-12 added i2c scanner code for the LCD with i2c backpack
2024-09-12 added sample code for the LCD screen
2024-09-13 added wifi manager for ESP32
2024-09-17 added code for the api that sends the internal temperature from the post request to the database for logging
2024-09-18 fritzing diagram for the updated ESP32 setup
    [RFID RC522.fzz]
2024-09-19 fixed embedded code for consistent card scanning and temperature logging
    [main.cpp]
2024-09-23 updated embedded technical documentation with up to date schematics
2024-09-23 added main goal and product requirements
    [RFID RC522.fzz]
2024-09-23 improved BOM
2024-09-26 added material & digital design to concept_design uxd
2024-10-02 added temperature data to the api_ref
2024-10-02 added esp32-32 folder for testing setting files over
2024-10-04 moved embedded logic to temp module for new ESP32
2024-10-04 changed pinout and changed necesary values for the new esp32
2024-10-04 changed LED pinout
2024-10-18 added front plate CAD
2024-10-18 front plate V0.2 with bigger hexagons
    [front-plate v0.2.3mf]
2024-10-18 front plate v0.3 and v0.4 with better margins and pin replacement
    [front-plate v0.1.3mf, front-plate v0.2.3mf, front-plate v0.3.3mf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]
2024-10-18 readjusting pins, filleting pins for stability and creating button cutouts for better fitting
    [front-plate v0.5.3mf]
2024-10-19 front-plate version 0.6 with shorter pins, rounded accents and final button placements
    [front-plate v0.6.3mf]
2024-10-19 added a rim around the front plate and a spot for the DTH11
    [front-plate v0.7.3mf]
2024-10-19 front-plate v0.8 made grid cleaner and symmetrical, changed dht11 placement for better fitting. removed fillet for future lcd extension
    [front-plate v0.8.3mf]
2024-10-19 added front and back plate construction, adjusted DHT11 holder and reduced pin size.
    [back-plate V0.9.3mf, front-plate V0.9.3mf]
2024-10-20 created more threshold in the backplate for a smoother attachments and realigned pins for the DHT11 for better clearance
    [back-plate v0.10.3mf, front-plate v0.10.3mf]
2024-10-20 changed the housing to have connectors with magnets and created an actual bottom plate for the back-plate to house the micro controlller with gaps for charging ports
    [back-plate v0.11.3mf, front-plate v0.11.3mf]
2024-10-20 added version 12 of the enclosing with better port positions more threshold for closing and better sizes for the magnets
    [back-plate v0.12.3mf, front-plate v0.12.3mf]
2024-10-20 added a solid place for the esp32, made holes bigger for the magnets. Made the latching more smooth, and tigthened dth11 placement. and made placement for buzzer
    [back-plate v0.13.3mf, front-plate v0.13.3mf]
2024-10-20 filleting edges for smoother device feel and look
    [back-plate v0.14.3mf, front-plate v0.14.3mf]
2024-10-20 added filleting to remove overhang on port cutouts
    [back-plate v0.15.3mf, front-plate v0.15.3mf]
2024-10-21 added version 1.0 of beertracker hub housing
    [Beertracker HUB Housing V1.0.3mf]
2024-10-21 added cad to documentation
    [Beertracker HUB Housing V1.0.3mf, RFID RC522.fzz, back-plate V0.9.3mf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]
2024-10-21 working RFID module code
    [RFID RC522.fzz]
2024-10-22 added first version of the LCD plate
    [LCD-plate v0.1.3mf]
2024-10-22 v0.2 of lcd bracket with better fittings
    [LCD-plate v0.2.3mf]
2024-10-23 moved esp32-32 to main IoT embedded folder
2024-10-24 LCD Plate covering front of LCD
    [LCD-plate V0.3.3mf]
2024-10-24 v0.4 of lcd with better tightness and pins to keep lcd in place
    [LCD-plate V0.4.3mf]
2024-10-24 initial button menu implementation
2024-10-24 updated button menu with sound queue and smoother button presses with shorter but snappy delay
    [main.cpp]
2024-10-25 added tolerances to backplate and added a backside of the plate for enclosure
    [LCD-plate v0.5.3mf]
2024-10-26 front-plate v0.16 with supporting structure for the lcd bracket
    [front-plate v0.16.3mf]
2024-10-26 LCD plating with rounded corners and less back extrusion
    [LCD-plate V0.6.3mf]
2024-10-27 LCD-plate V0.7 has better tolerances for the mounting and slimmer design body design
    [LCD-plate V0.7.3mf]
2024-10-27 Beertracker HUB Housing V1.2 | NEW LCD Housing, better component placing, cable routing
    [Beertracker HUB Housing V1.2.3mf]
2024-10-28 added lcd housing to concept_design documentation
2024-10-28 using https tunnel for ip address in esp32 code
2024-10-28 Beertracker HUB housing v1.3 | Added theming
    [Beertracker HUB Housing V1.3.3mf]
2024-10-31 added mac and ipv4 address of device to website
2024-11-01 fixed double error issue on card scanning session handler
    [main.cpp]
2024-11-02 spacing between edit and delete button
2024-11-02 added custom error messages
    [main.cpp]
2024-11-04 added video of printing process
2024-11-05 implemented HTTP server on esp32 with a reset function on the website
    [main.cpp]
2024-11-07 added a place for kicad
2024-11-24 Add GitHub Actions for MkDocs deployment
    [beertracker_hub.kicad_pcb, beertracker_hub.kicad_sch]
2024-11-24 les do this
2024-12-30 added config.h for credentials for the esp32
2024-12-30 added PCB design
    [Beertracker HUB PCB.kicad_pcb, Beertracker HUB PCB.kicad_sch, beertracker_hub.kicad_pcb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]
2024-12-31 added the OLED screen implemenation withhe U8g2 library
    [Beertracker HUB PCB.kicad_pcb]
2024-12-31 added a duplicate folder for the v1.0
    [Beertracker HUB PCB.kicad_pcb, Beertracker HUB PCB.kicad_sch]
2025-01-01 finalized and ordered PCB design, changed code to be OLED screen orientated
    [Beertracker HUB PCB.kicad_pcb, Beertracker HUB PCB.kicad_sch, Beertracker HUB PCB.step]
